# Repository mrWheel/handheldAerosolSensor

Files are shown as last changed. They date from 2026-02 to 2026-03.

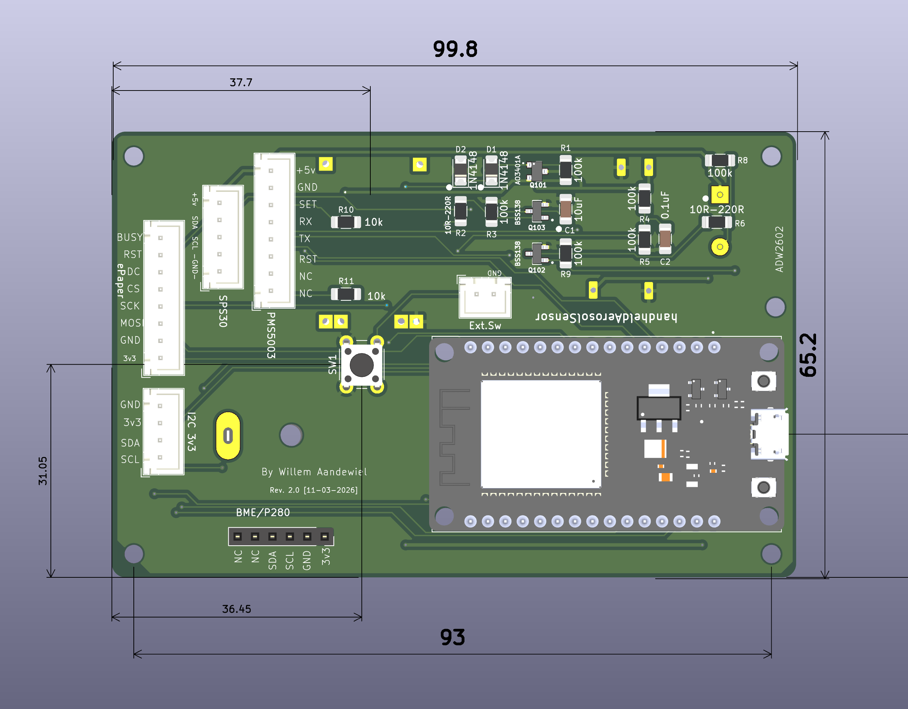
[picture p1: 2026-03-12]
documents/handheldAerosolSensorPCB.png

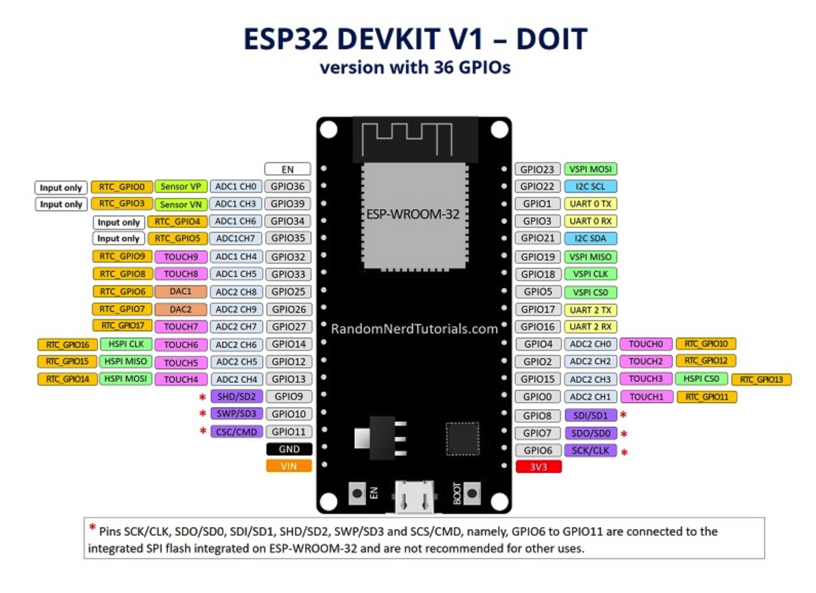
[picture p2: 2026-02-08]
documents/ESP32 DEVKIT V1 (36pins).png

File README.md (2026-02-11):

# Low-Power Air Quality Monitor (SPS30 + E-Paper)

## Disclaimer
This software is developed incrementally. That means I have no clear idea how it works (though it *mostly* does).

If you have questions about this software, it will probably take you just as long to figure things out as it would take me. So I’d prefer that you investigate it yourself.

Having said that **Don’t Even Think About Using It**

Seriously. Don’t.

Building this design may injure or kill you during construction, burn your house down while in use, and then—just to be thorough—explode afterward.

This is **not** a joke. This project involves **lethal voltages**. If you are not a **qualified electronics engineer**, close this repository, step away from the soldering iron, and make yourself a cup of tea.

If you decide to ignore all of the above and build it anyway, you do so **entirely at your own risk**. You are fully responsible for taking proper safety precautions. I take **zero responsibility** for anything that happens—electrically, mechanically, chemically, spiritually, or otherwise.

Also, full disclosure: I am **not** a qualified electrical engineer. I provide **no guarantees**, **no warranties**, and **absolutely no assurance** that this design is correct, safe, or suitable for any purpose whatsoever.

# What it is
This project is a **battery-powered, low-power air quality monitor** based on:

- **ESP32 DEVKIT V1**
- **Sensirion SPS30** particulate matter sensor (I²C)
- **1.54" black/white e‑paper display (200×200)**
- **High-side power latch** using a P‑channel MOSFET + 2N7000 or BSS138
- **Single-cell Li‑ion (18650)** battery with DC/DC boost to 5 V

The system powers itself on with a button, performs a measurement cycle, updates the e‑paper display, and then **fully powers itself off** to achieve near-zero standby current.

---

## Features

- True hardware power-off (no sleep leakage)
- SPS30 warm-up with countdown on e‑paper
- Configurable number of measurement attempts
- **Only valid sensor samples are averaged**
- PM1.0 / PM2.5 / PM10 display
- Simple air-quality classification (PM2.5 based)
- Battery voltage and percentage display

---

## Measurement Flow

1. User presses power button
2. Power latch engages
3. E‑paper resets and shows status
4. SPS30 starts measurement
5. Warm-up delay (default: 15 s)
6. Up to `maxMetingen` measurement attempts
   - Only valid samples are accumulated
7. Average values are calculated
8. Results are shown on the e‑paper
9. SPS30 is stopped
10. Power latch is released (device turns fully off)

---

## Hardware Connections

### ESP32 DevKit V1 - Pin mapping for AerosolSensor

| ESP32 pin | DEVKIT V1 | Standaard functie | AerosolSensor | Opmerking |
|---|---|---|---|---|
| 25 | D25 | GPIO / DAC1 | GPIO_PIN_LATCH | Latch control (OUTPUT) |
| 33 | D33 | GPIO / ADC1_CH5 / Touch | GPIO_PIN_SWITCH | Switch input (INPUT_PULLUP), non-strapping |
| 34 | D34 | ADC1_CH6 (input-only) | GPIO_PIN_BAT_ADC | Battery ADC (input-only), ADC1 recommended |
| 21 | D21 | I2C SDA (typical) | GPIO_PIN_SPS30_SDA | SPS30 SDA |
| 22 | D22 | I2C SCL (typical) | GPIO_PIN_SPS30_SCL | SPS30 SCL |
| 16 | RX2 | Future Ext. | GPIO_PIN_SPS_UART_RX | Serial SPS module |
| 17 | TX2 | Future Ext. | GPIO_PIN_SPS_UART_TX | Serial SPS module | 
| 23 | D23 | VSPI MOSI (typical) | GPIO_PIN_EPD_MOSI | E-paper DIN (MOSI) |
| -1 | n.c. | n.v.t. | GPIO_PIN_EPD_MISO | Not connected on display |
| 18 | D18 | VSPI SCK (typical) | GPIO_PIN_EPD_SCK | E-paper CLK (SCK) |
| 27 | D27 | GPIO | GPIO_PIN_EPD_CS | E-paper CS |
| 19 | D19 | e-Paper DC | GPIO_PIN_EPD_DC | E-paper DC |
| 13 | D13 | e-Paper RST | GPIO_PIN_EPD_RST | E-paper RST |
| 32 | D32 | GPIO / ADC1_CH4 / Touch | GPIO_PIN_EPD_BUSY | E-paper BUSY (INPUT_PULLUP), non-strapping |
| 14 | D14 | GPIO PWM Touch | GPIO_PIN_BUZZER_PWM  | Buzzer 

### Battery Measurement

- 100 kΩ / 100 kΩ divider from battery to D34
- Optional 100 nF capacitor from D34 to GND

---

## Software Stack

- **PlatformIO**
- **Arduino framework**
- **Libraries**
  - GxEPD2
  - Adafruit GFX
  - Adafruit BMP280 Library
  - Adafruit Unified Sensor
  - Sensirion SPS30 (GitHub)
  - safeTimers

---

## PlatformIO Configuration

```ini
; platformio.ini
;
;— ESP32 + Arduino framework
;— Pin choices avoid ESP32 strapping pins (GPIO0,2,4,5,12,15) and flash pins (GPIO6–11).
;— Battery ADC uses ADC1 (GPIO34) so it keeps working even if WiFi were enabled.
;— SPI uses VSPI defaults for ESP32: MOSI=23, MISO=19, SCK=18.

[platformio]
workspace_dir = .pio.nosync
default_envs = esp32dev

[env:esp32dev]
platform = espressif32
board = esp32dev
framework = arduino

monitor_speed = 115200
upload_speed = 921600

;-- do NOT use 0, 2, 4, 5, 12, 15 (Strapping pins) or 6–11 (Flash pins)
build_flags =
  ;==================== Power & user input ====================
  ;— Power latch control (OUTPUT)
  -D GPIO_PIN_LATCH=25

  ;— User pushbutton (INPUT_PULLUP, LOW = pressed)
  -D GPIO_PIN_SWITCH=33

  ;==================== Battery measurement ====================
  ;— Battery voltage divider ADC input (ADC1)
  -D GPIO_PIN_BAT_ADC=34

  ;==================== SPS air quality sensor ====================
  ;— SPS I2C interface
  -D GPIO_PIN_SPS_SDA=21
  -D GPIO_PIN_SPS_SCL=22

  ;— SPS UART interface (UART2, hardware default pins)
  -D GPIO_PIN_SPS_UART_TX=17
  -D GPIO_PIN_SPS_UART_RX=16

  ;==================== E-paper display (SPI) ====================
  ;— SPI data pins (VSPI defaults)
  -D GPIO_PIN_EPD_MOSI=23
  -D GPIO_PIN_EPD_MISO=-1
  -D GPIO_PIN_EPD_SCK=18

  ;— E-paper control pins
  -D GPIO_PIN_EPD_CS=27
  -D GPIO_PIN_EPD_DC=19
  -D GPIO_PIN_EPD_RST=13
  -D GPIO_PIN_EPD_BUSY=32

  ;==================== User feedback ====================
  ;— Piezo buzzer (PWM via LEDC)
  -D GPIO_PIN_BUZZER_PWM=14

  ;==================== Application configuration ====================
  -D WARMUP_SECONDS=5
  -D MAX_METINGEN=5

  ;==================== ADC calibration ====================
  -D ADC_VREF_VOLTAGE=3.30f
  
  ;==================== Battery calibration ====================
  -D BAT_CAL_GAIN=0.94245f
  -D BAT_CAL_OFFSET=0.48763f

  ;==================== Library configuration ====================
  -D DISABLE_DIAGNOSTIC_OUTPUT

lib_deps =
  zinggjm/GxEPD2@^1.6.5
  adafruit/Adafruit GFX Library@^1.11.9
  adafruit/Adafruit BMP280 Library
	adafruit/Adafruit Unified Sensor
  https://github.com/Sensirion/arduino-sps.git
  https://github.com/mrWheel/safeTimers.git
```

---

## Power Latch Notes

- Upload firmware with **stable power** (USB directly)
- During normal operation the latch cuts power completely
- GPIO D25 must be set HIGH early in `setup()` to hold power

---

## Customization

You can easily adjust:

- `warmupSeconds` (e.g. 15 → 30)
- `maxMetingen` (e.g. 5 → 10)
- PM2.5 thresholds for status classification
- Display layout and fonts

---

## License

This project is intended for personal and educational use.
You are free to modify and adapt it for your own hardware.

---

## Notes

This design prioritizes:
- Measurement correctness
- Ultra-low standby power
- Robust behavior on battery power

It is well suited for **portable or infrequently-used air quality measurements** where long battery life matters.

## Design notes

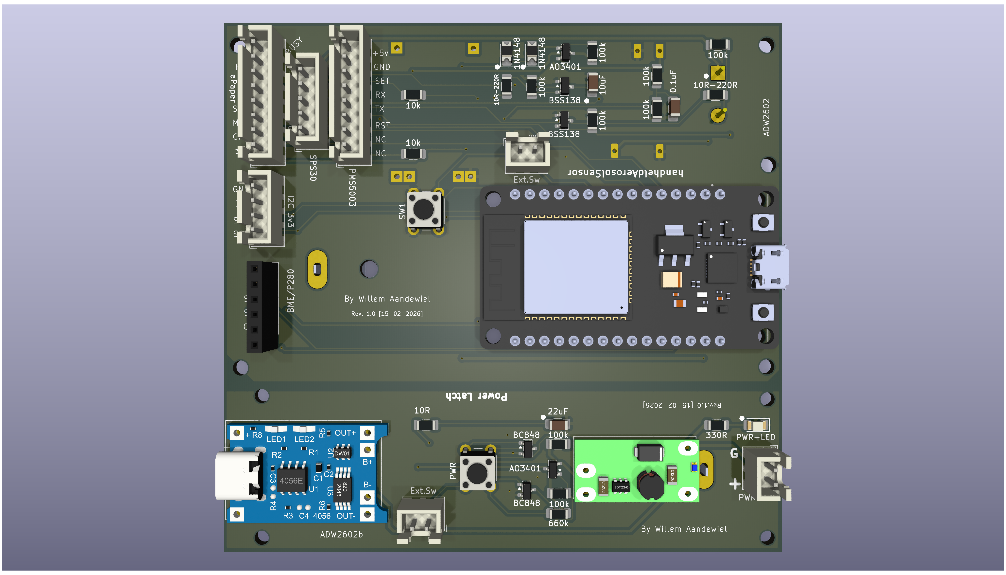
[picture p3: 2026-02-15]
documents/hAS_Top.png

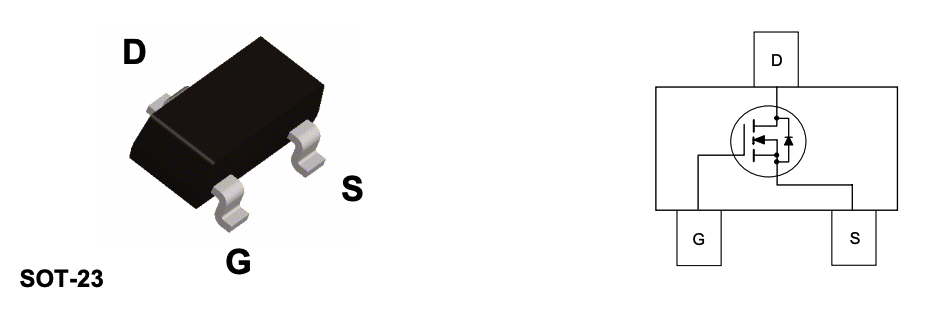
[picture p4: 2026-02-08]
documents/BSS138.png

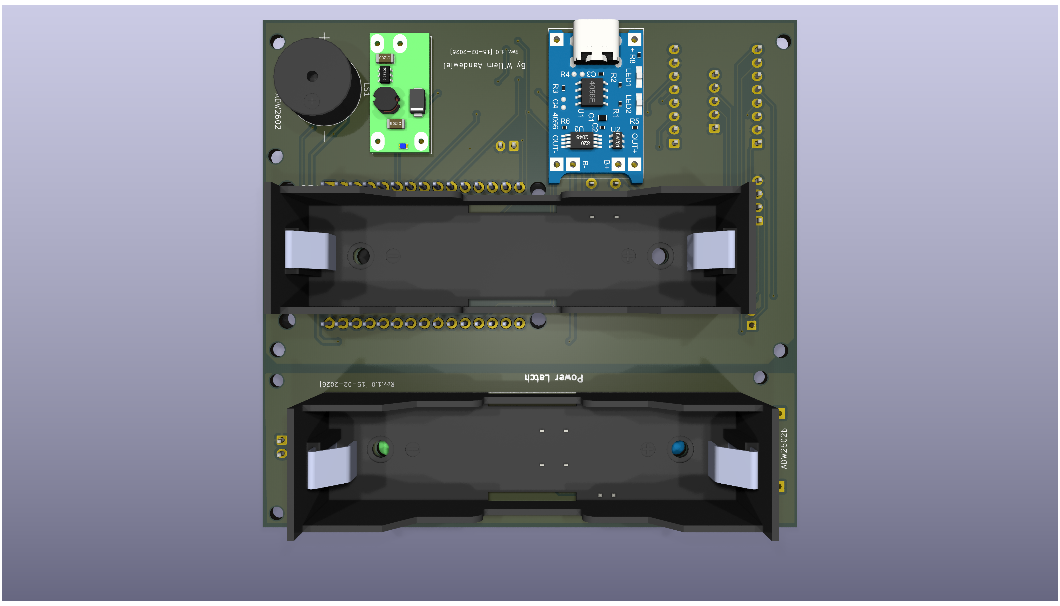
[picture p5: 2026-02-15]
documents/hAS_Bottom.png

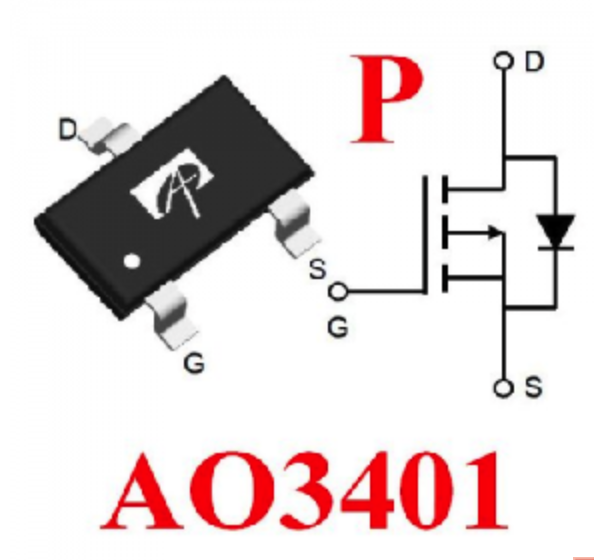
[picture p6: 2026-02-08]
documents/AO3401.png

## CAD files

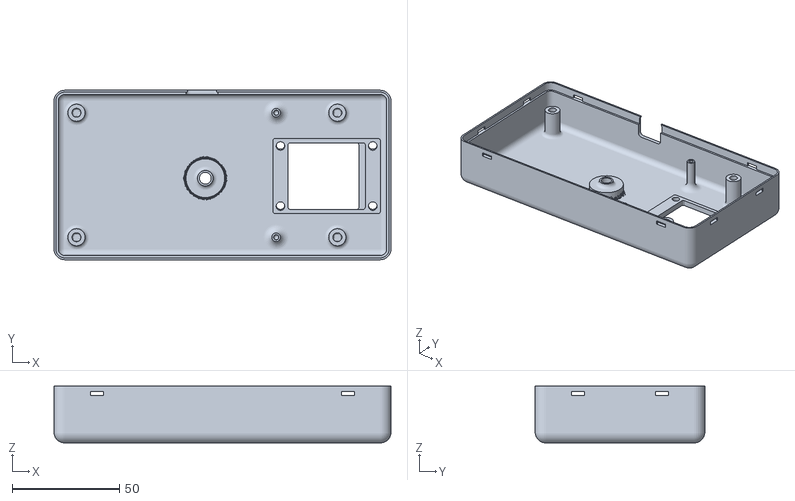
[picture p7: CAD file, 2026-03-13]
3Dfiles/handheldAerosolSensorLid.stl
157.0 x 79.0 x 26.5

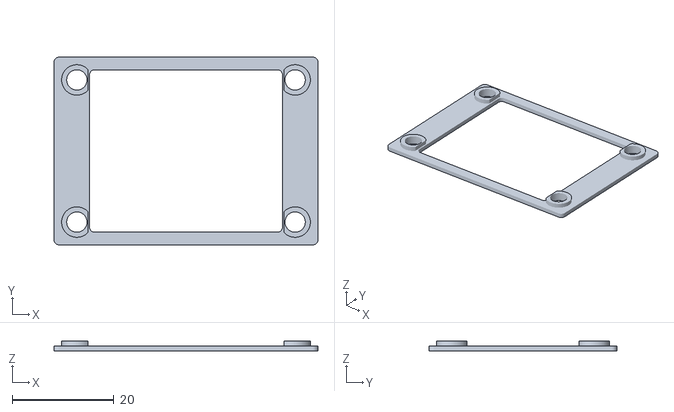
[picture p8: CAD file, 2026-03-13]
documents/ePaper.stl
52.0 x 37.0 x 2.00

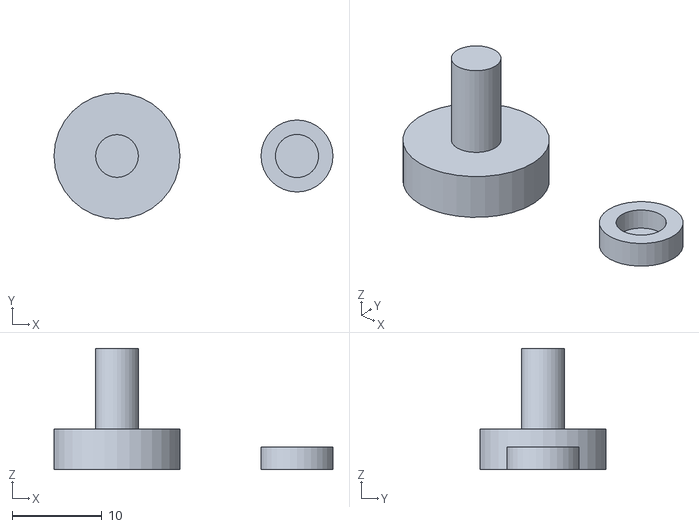
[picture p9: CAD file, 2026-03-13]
3Dfiles/handheldAerosolSensorButton.stl
31.0 x 14.0 x 13.5

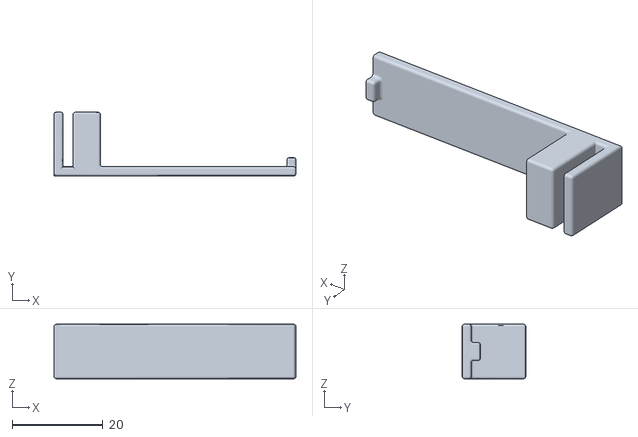
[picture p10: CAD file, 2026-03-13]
documents/SPS30Holder.stl
53.2 x 14.0 x 12.0

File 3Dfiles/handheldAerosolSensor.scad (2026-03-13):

//-----------------------------------------------------------------------
// Yet Another Parameterized Projectbox generator
//
//  This is a box for a handheldAerosolSensor
//
//  Version 1.0.0 (13-03-2026)
//
// This design is parameterized based on the size of a PCB.
//
// For many/complex cutoutGrills, you might need to adjust
//  the max number of elements in OpenSCAD:
//
//      Preferences->Advanced->Turn off rendering at 250000 elements
//                                                   ^^^^^^
//
//-----------------------------------------------------------------------

include <./YAPPgenerator_v3.3.8.scad>

$fn=20;

myPcb    = "../documents/handheldAerosolSensorPCB.stl"; 
myEpaper = "../documents/ePaper.stl"; 

if (false)
{
  translate([56.8, 39.5 , 25.7]) 
  {
    rotate([0,0,180]) color("gray") import(myPcb);
  }
}

if (false)
{
  translate([127, 138,0]) 
  {
    rotate([0,0,180]) color("black") import(myEpaper);
  }
}

//---------------------------------------------------------
// This design is parameterized based on the size of a PCB.
//---------------------------------------------------------
// Note: length/lengte refers to X axis, 
//       width/breedte refers to Y axis,
//       height/hoogte refers to Z axis

/*
      padding-back|<------pcb length --->|<padding-front
                            RIGHT
        0    X-axis ---> 
        +----------------------------------------+   ---
        |                                        |    ^
        |                                        |   padding-right 
      Y |                                        |    v
      | |    -5,y +----------------------+       |   ---              
 B    a |         | 0,y              x,y |       |     ^              F
 A    x |         |                      |       |     |              R
 C    i |         |                      |       |     | pcb width    O
 K    s |         |                      |       |     |              N
        |         | 0,0              x,0 |       |     v              T
      ^ |    -5,0 +----------------------+       |   ---
      | |                                        |    padding-left
      0 +----------------------------------------+   ---
        0    X-as --->
                          LEFT
*/


//-- which part(s) do you want to print?
printBaseShell        = true;
printLidShell         = true;
printSwitchExtenders  = true;
printDisplayClips     = false;

// ********************************************************************
// The Following will be used as the first element in the pbc array

//Defined here so you can define the "Main" PCB using these if wanted
pcbLength           = 100; // front to back (X axis)
pcbWidth            =  65; // side to side (Y axis)
pcbThickness        = 1.7; 
standoffHeight      = 22; //10.1; //-- How much the PCB needs to be raised from the base to leave room for solderings and whatnot
standoffDiameter    = 4;
standoffPinDiameter = 2.0;
standoffHoleSlack   = 0.4;

//===================================================================
// *** PCBs ***
// Printed Circuit Boards
//-------------------------------------------------------------------
//  Default origin =  yappCoordPCB : yappCoordBoxInside[0,0,0]
//
//  Parameters:
//   Required:
//    p(0) = name
//    p(1) = length
//    p(2) = width
//    p(3) = posx
//    p(4) = posy
//    p(5) = Thickness
//    p(6) = standoff_Height = Height to bottom of PCB from the inside of the base
//             negative measures from inside of the lid to the top of the PCB
//    p(7) = standoff_Diameter
//    p(8) = standoff_PinDiameter
//   Optional:
//    p(9) = standoff_HoleSlack (default to 0.4)

//The following can be used to get PCB values elsewhere in the script - not in pcb definition. 
//If "PCB Name" is omitted then "Main" is used
//  pcbLength           --> pcbLength("PCB Name")
//  pcbWidth            --> pcbWidth("PCB Name")
//  pcbThickness        --> pcbThickness("PCB Name") 
//  standoffHeight      --> standoffHeight("PCB Name") 
//  standoffDiameter    --> standoffDiameter("PCB Name") 
//  standoffPinDiameter --> standoffPinDiameter("PCB Name") 
//  standoffHoleSlack   --> standoffHoleSlack("PCB Name") 

pcb = 
[
  // Default Main PCB - DO NOT REMOVE the "Main" line.
  //-- 0,          1,        2, 3, 4,            5,              6,                7,                   8, 9
  ["Main", pcbLength, pcbWidth, 0, 0, pcbThickness, standoffHeight, standoffDiameter, standoffPinDiameter, standoffHoleSlack]
  //--   0,   1,  2,   3, 4, 5,  6, 7, 8, 9
 ,["ePaper", 33, 48, 100, 9, 3, -0.1, 5, 2, 0.5]

];

//-------------------------------------------------------------------                            
//-- padding between pcb and inside wall
paddingFront        = 15;
paddingBack         = 5;
paddingRight        = 5;
paddingLeft         = 5;

//-- Edit these parameters for your own box dimensions
wallThickness       = 2.0;
basePlaneThickness  = 2.0;
lidPlaneThickness   = 2.0;

//-- Total height of box = lidPlaneThickness 
//                       + lidWallHeight 
//--                     + baseWallHeight 
//                       + basePlaneThickness
//-- space between pcb and lidPlane :=
//--      (bottonWallHeight+lidWallHeight) - (standoffHeight+pcbThickness)
baseWallHeight      = 20;
lidWallHeight       = 20;

//-- ridge where base and lid off box can overlap
//-- Make sure this isn't less than lidWallHeight
ridgeHeight         = 5.0;
ridgeSlack          = 0.2; // Gap between the inside of the lid and the outside of the base
//New in v3.3.7 
ridgeGap            = 0.5; // Gap between the bottom of the base ridge and the bottom of the lid when assembled.
roundRadius         = 5.0;

// Box Types are 0-4 with 0 as the default
// 0 = All edges rounded with radius (roundRadius) above
// 1 = All edges sqrtuare
// 2 = All edges chamfered by (roundRadius) above 
// 3 = Square top and bottom edges (the ones that touch the build plate) and rounded vertical edges
// 4 = Square top and bottom edges (the ones that touch the build plate) and chamfered vertical edges
// 5 = Chanfered top and bottom edges (the ones that touch the build plate) and rounded vertical edges
boxType             = 0; // Default type 0

// Set the layer height of your printer
printerLayerHeight  = 0.2;


//---------------------------
//--     C O N T R O L     --
//---------------------------
// -- Render --
renderQuality             = 8;          //-> from 1 to 32, Default = 8

// --Preview --
previewQuality            = 5;          //-> from 1 to 32, Default = 5
showSideBySide            = true;       //-> Default = true
onLidGap                  = 1;  // tip don't override to animate the lid opening
colorLid                  = "YellowGreen";   
alphaLid                  = 1;
colorBase                 = "BurlyWood";
alphaBase                 = 1;
hideLidWalls              = false;      //-> Remove the walls from the lid : only if preview and showSideBySide=true 
hideBaseWalls             = false;      //-> Remove the walls from the base : only if preview and showSideBySide=true  
showOrientation           = true;       //-> Show the Front/Back/Left/Right labels : only in preview
showPCB                   = false;      //-> Show the PCB in red : only in preview 
showSwitches              = false;      //-> Show the switches (for pushbuttons) : only in preview 
showButtonsDepressed      = false;      //-> Should the buttons in the Lid On view be in the pressed position
showOriginCoordBox        = false;      //-> Shows red bars representing the origin for yappCoordBox : only in preview 
showOriginCoordBoxInside  = false;      //-> Shows blue bars representing the origin for yappCoordBoxInside : only in preview 
showOriginCoordPCB        = false;      //-> Shows blue bars representing the origin for yappCoordBoxInside : only in preview 
showMarkersPCB            = false;      //-> Shows black bars corners of the PCB : only in preview 
showMarkersCenter         = false;      //-> Shows magenta bars along the centers of all faces  
inspectX                  = 0;          //-> 0=none (>0 from Back)
inspectY                  = 0;          //-> 0=none (>0 from Right)
inspectZ                  = 0;          //-> 0=none (>0 from Bottom)
inspectXfromBack          = true;       //-> View from the inspection cut foreward
inspectYfromLeft          = true;       //-> View from the inspection cut to the right
inspectZfromBottom        = true;       //-> View from the inspection cut up
//---------------------------
//--     C O N T R O L     --
//---------------------------

//-------------------------------------------------------------------
//-------------------------------------------------------------------
// Start of Debugging config (used if not overridden in template)
// ------------------------------------------------------------------
// ------------------------------------------------------------------
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

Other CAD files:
3Dfiles/YAPPgenerator_v3.3.8.scad
3Dfiles/YAPPgenerator_v3.0.2.scad

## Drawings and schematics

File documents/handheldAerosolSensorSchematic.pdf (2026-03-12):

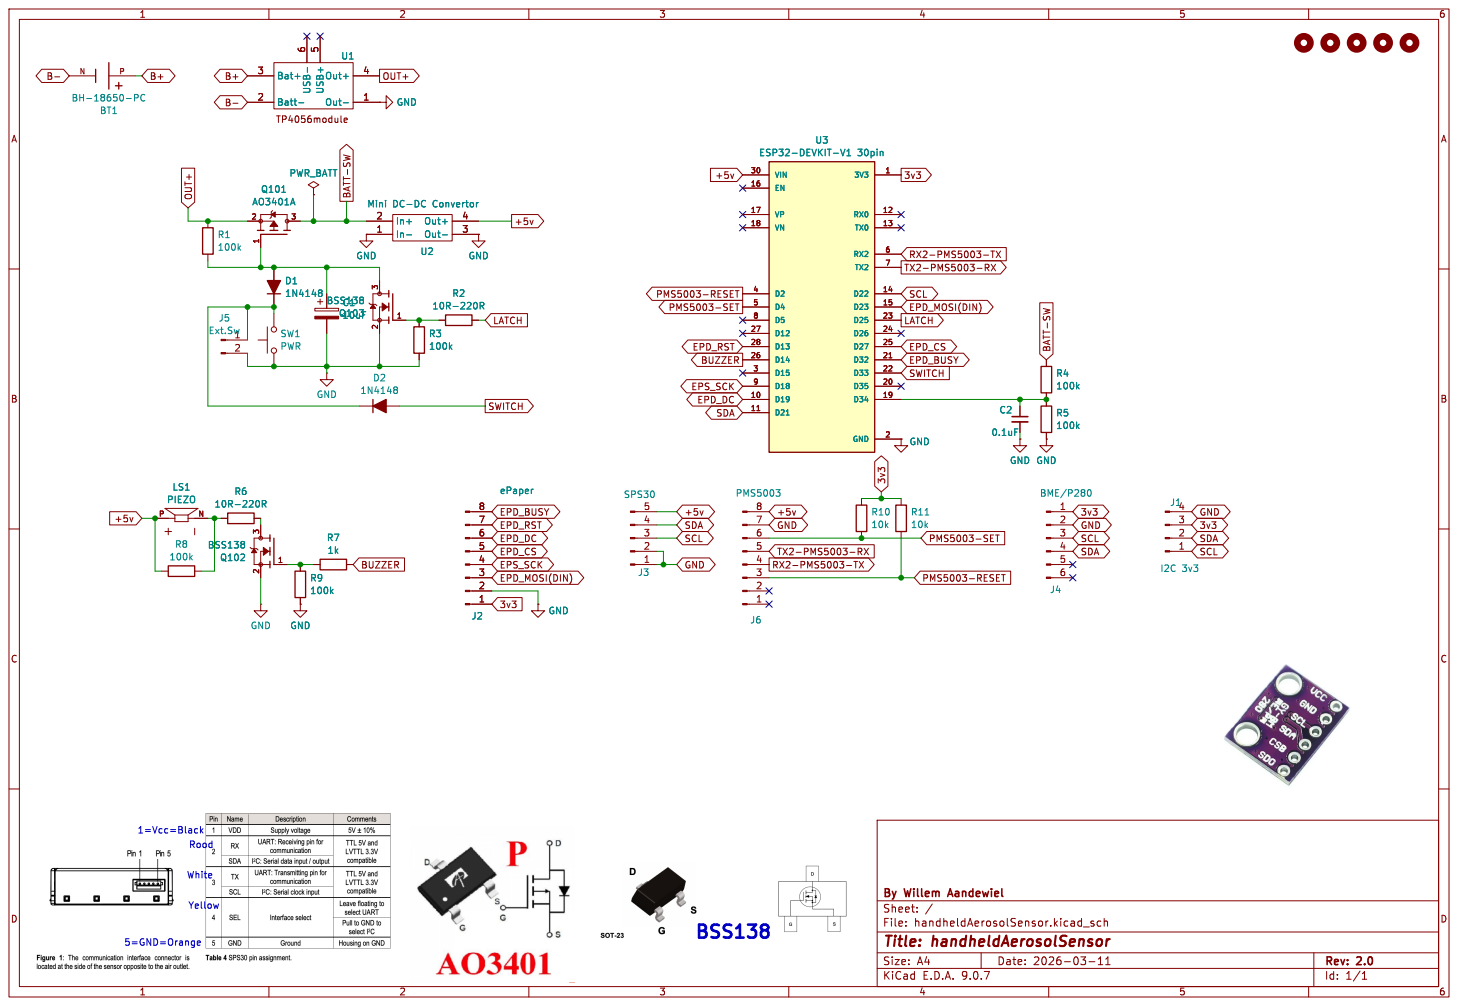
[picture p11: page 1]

Id: 1/1 Title: handheldAerosolSensor File: handheldAerosolSensor.kicad_sch Sheet: / By Willem Aandewiel

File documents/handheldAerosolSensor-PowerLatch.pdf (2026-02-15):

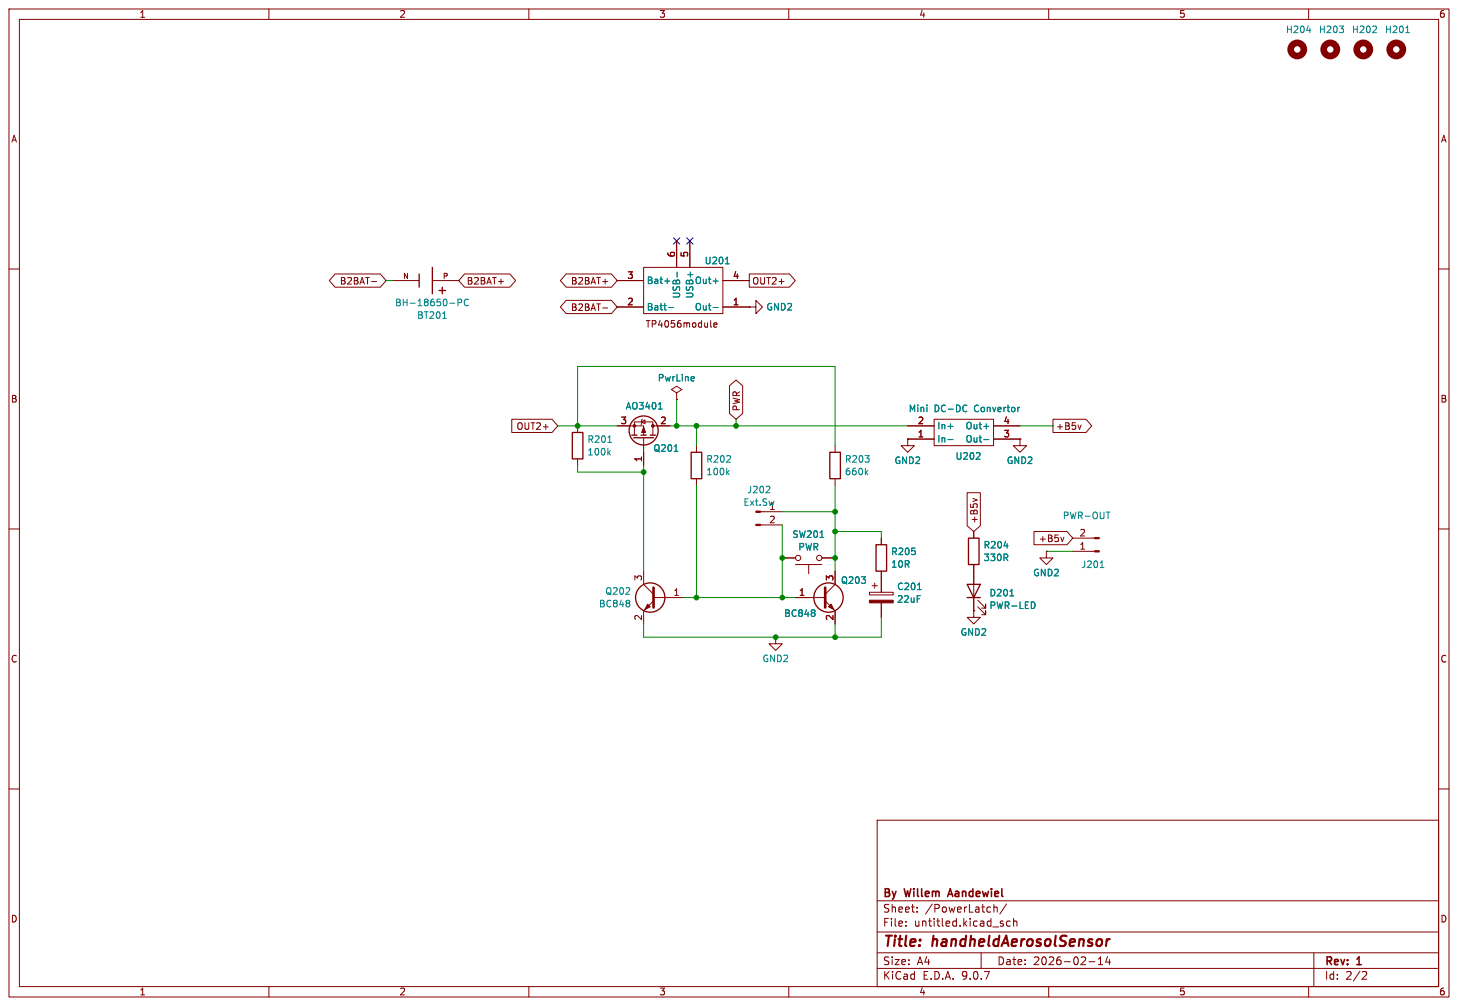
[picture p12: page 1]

5 USB- 6 Batt- 2 Bat+ 3 U201 PwrLine GND2 +B5v B2BAT+ B2BAT- +B5v +B5v B2BAT- B2BAT+ OUT2+ OUT2+ PWR Q201 AO3401

5 USB- 6 Batt- 2 Bat+ 3 PwrLine GND2 Q203 BC848

Id: 2/2 Title: handheldAerosolSensor File: untitled.kicad_sch Sheet: /PowerLatch/ By Willem Aandewiel

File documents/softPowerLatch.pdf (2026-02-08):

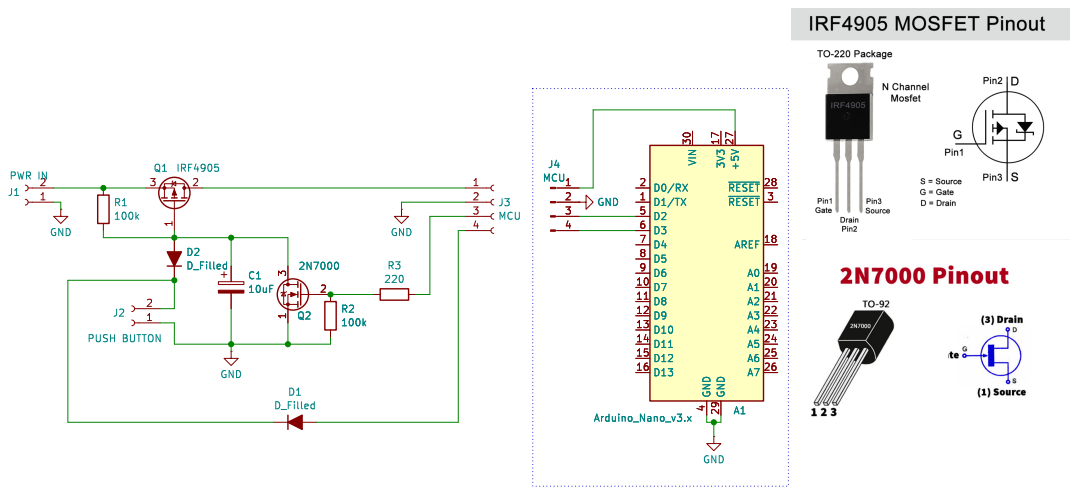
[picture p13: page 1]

Id: 1/1 Title: File: softPowerLatch.kicad_sch Sheet: /

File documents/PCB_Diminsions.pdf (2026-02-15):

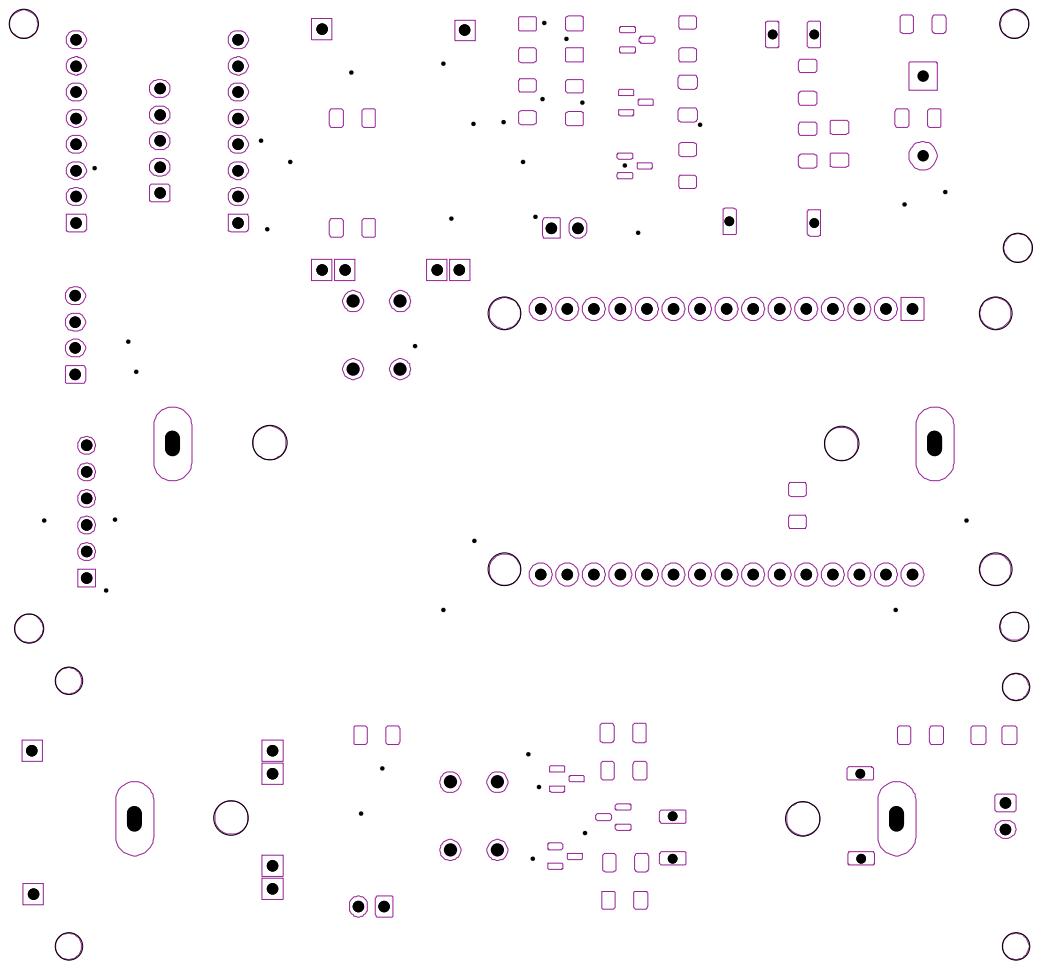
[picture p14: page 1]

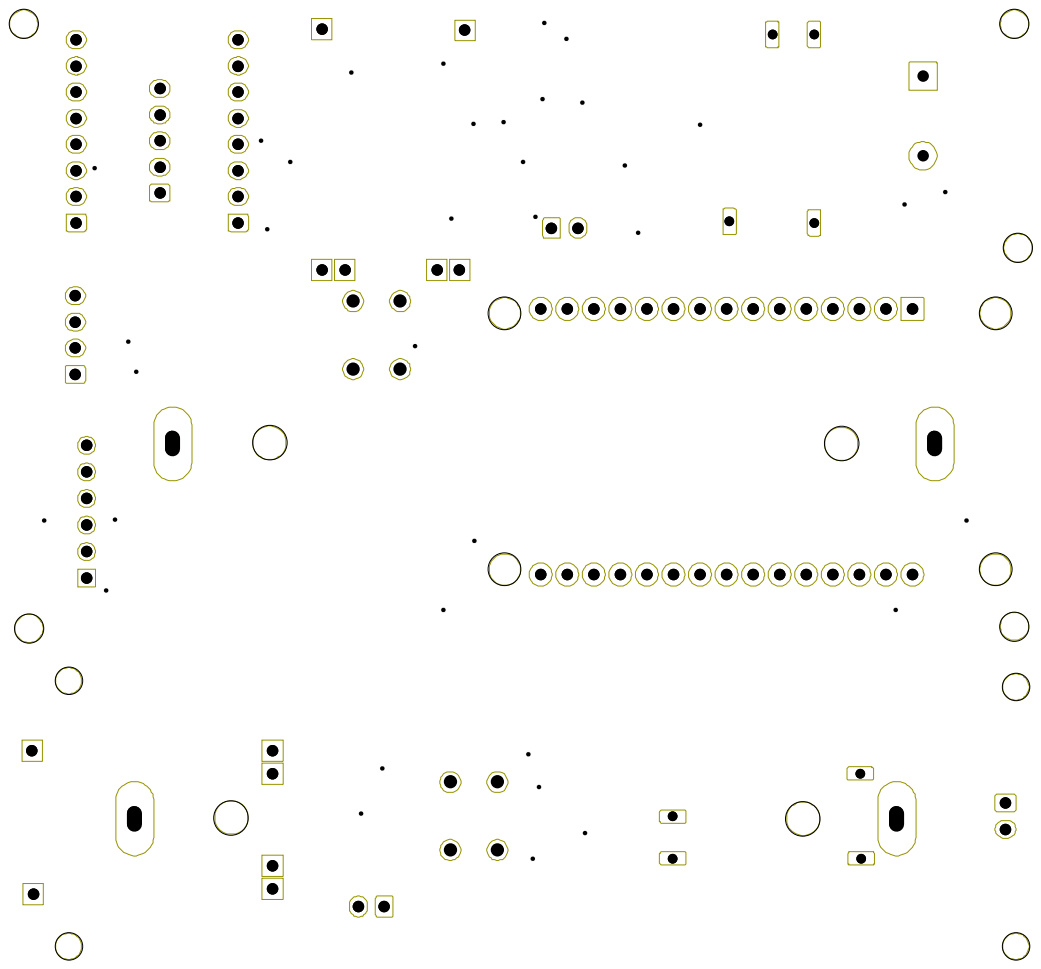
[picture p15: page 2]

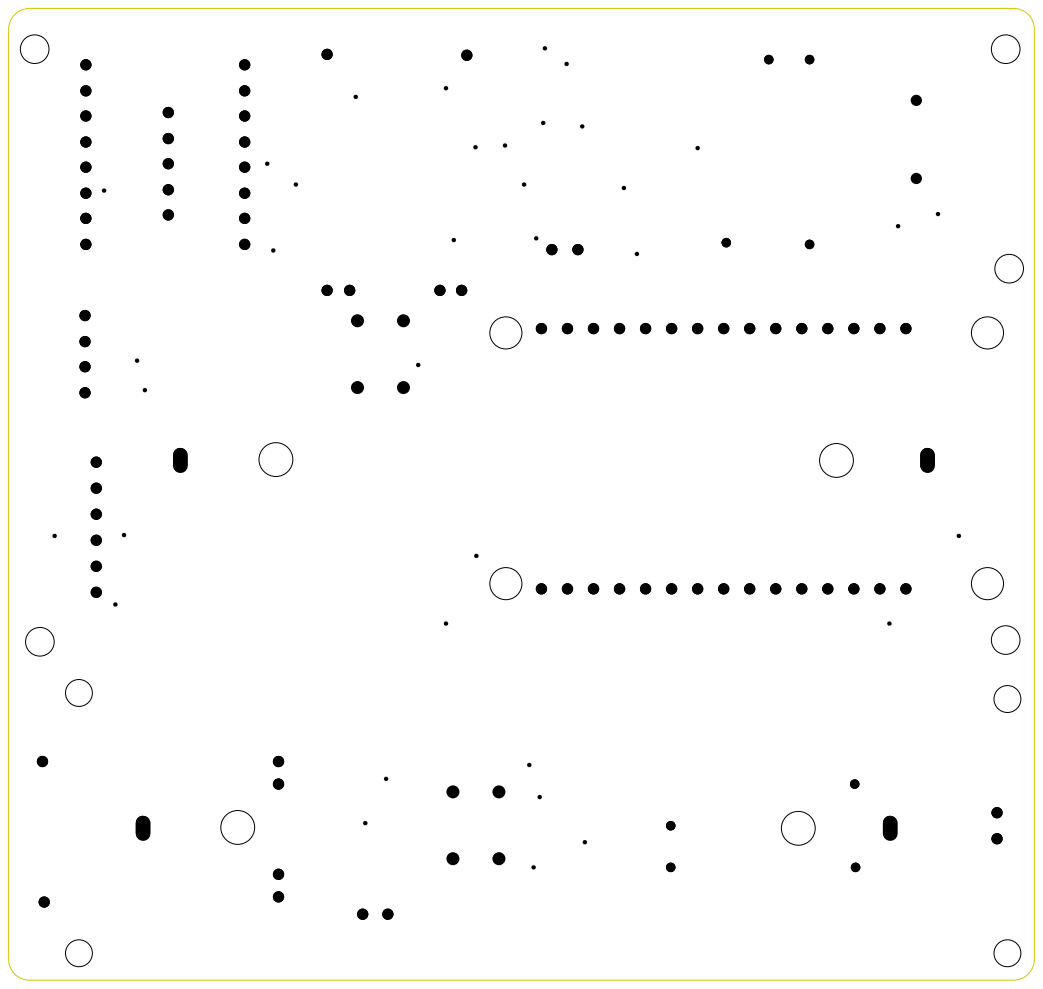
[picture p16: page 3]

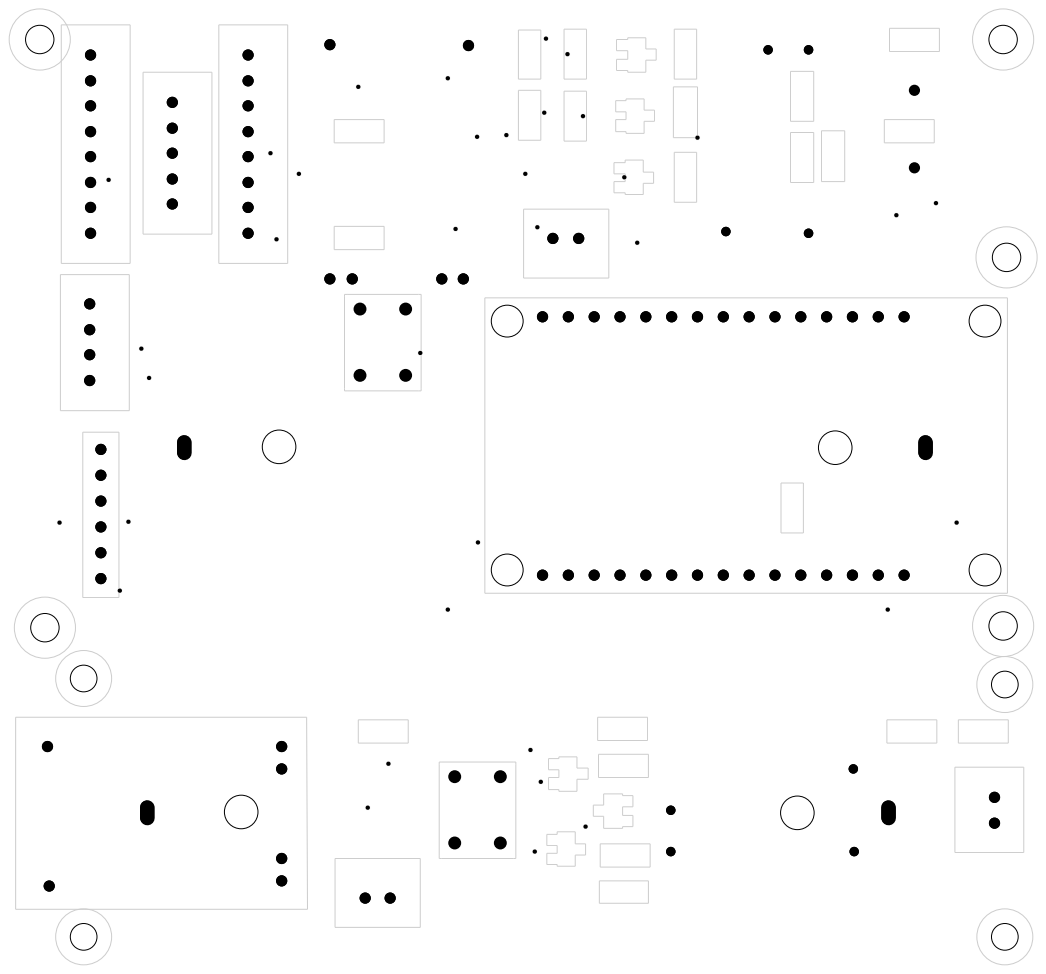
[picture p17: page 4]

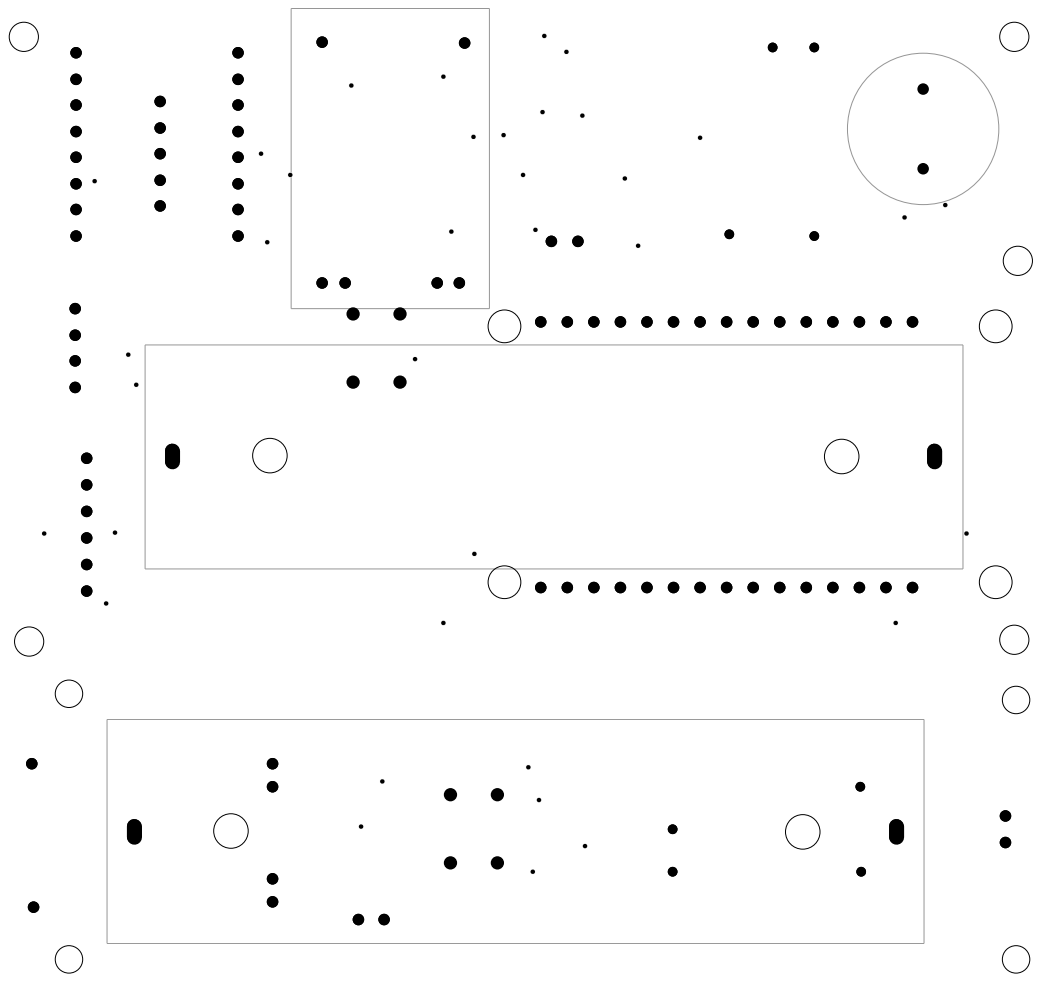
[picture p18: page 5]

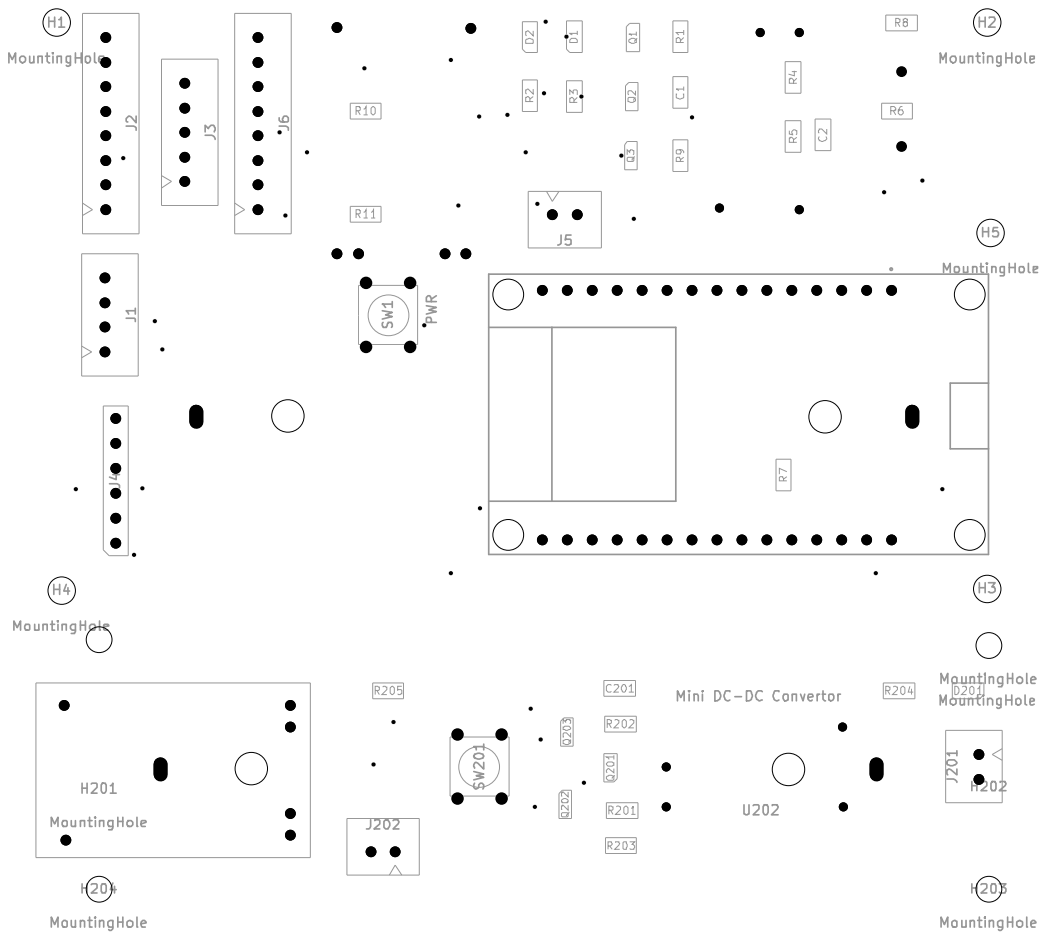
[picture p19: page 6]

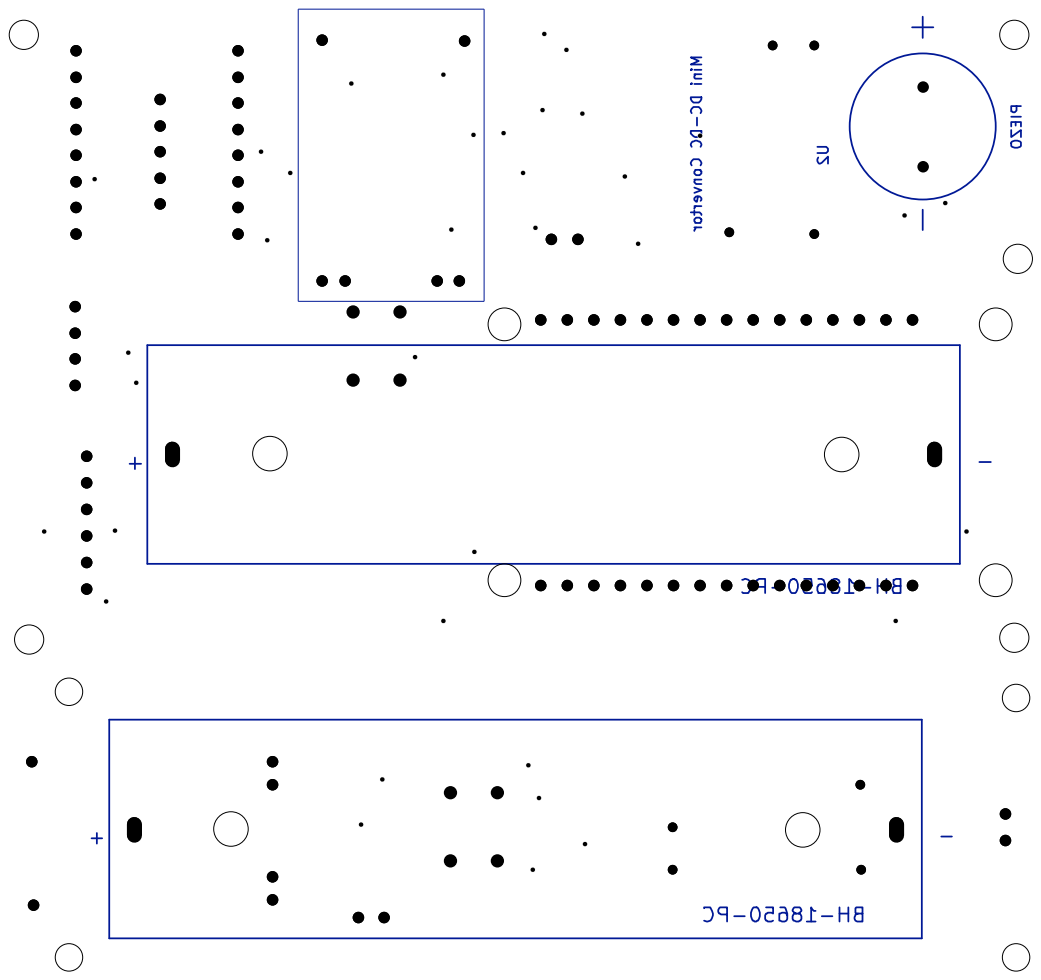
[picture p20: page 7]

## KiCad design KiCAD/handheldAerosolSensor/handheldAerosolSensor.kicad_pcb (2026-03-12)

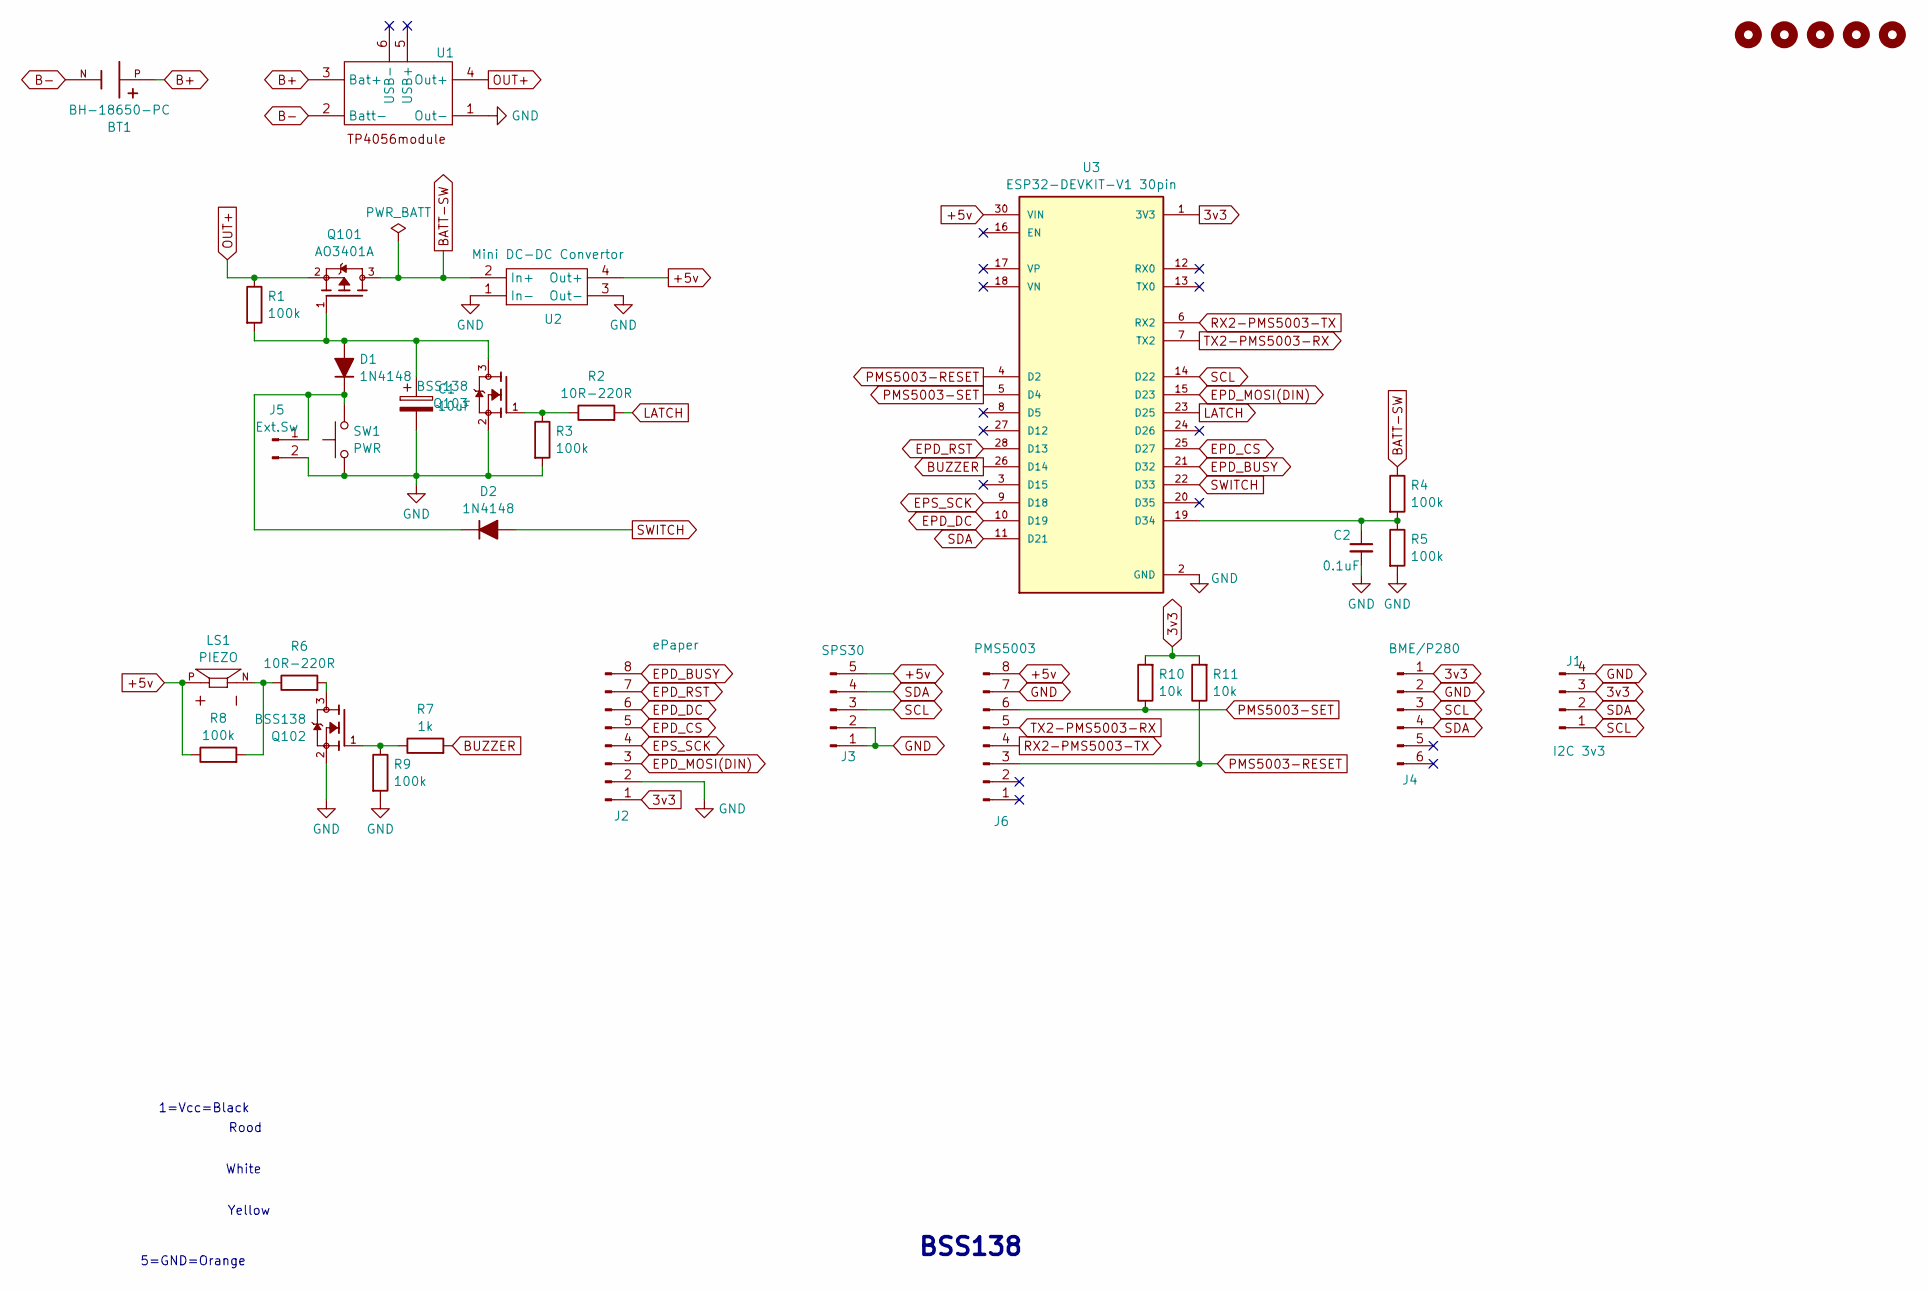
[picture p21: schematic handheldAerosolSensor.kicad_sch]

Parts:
BT1: BH-18650-PC; BAT_BH-18650-PC; PARTREV 05/17/19
C1: 10uF; C_1206_3216Metric_Pad1.33x1.80mm_HandSolder
C2: 0.1uF; C_1206_3216Metric_Pad1.33x1.80mm_HandSolder
D1, D2: 1N4148; D_1206_3216Metric_Pad1.42x1.75mm_HandSolder
H1, H2, H3, H4, H5: MountingHole; MountingHole_2.7mm
J1: I2C 3v3; JST_XH_B4B-XH-A_1x04_P2.50mm_Vertical
J2: ePaper; JST_XH_B8B-XH-A_1x08_P2.50mm_Vertical
J3: SPS30; JST_XH_B5B-XH-A_1x05_P2.50mm_Vertical
J4: BME/P280; PinSocket_1x06_P2.54mm_Vertical
J5: Ext.Sw; JST_XH_B2B-XH-A_1x02_P2.50mm_Vertical
J6: PMS5003; JST_XH_B8B-XH-A_1x08_P2.50mm_Vertical
LS1: PIEZO; XDCR_CPI-148-24-90T-67; PARTREV 1
Q101: AO3401A; AO3401
Q102, Q103: BSS138; PARTREV 30 Jan 2018
R1, R3, R4, R5, R8, R9: 100k; R_1206_3216Metric_Pad1.30x1.75mm_HandSolder
R2, R6: 10R-220R; R_1206_3216Metric_Pad1.30x1.75mm_HandSolder
R7: 1k; R_1206_3216Metric_Pad1.30x1.75mm_HandSolder
R10, R11: 10k; R_1206_3216Metric_Pad1.30x1.75mm_HandSolder
SW1: PWR; SW_PUSH_6mm_H4.3mm
U1: TP4056_USB-Charger_Board
U2: Mini DC-DC Convertor; Mini DC-DC Boost Convertor
U3: ESP32-DEVKIT-V1 30pin; MODULE_ESP32_DEVKIT_V1_30pin; PARTREV N/A

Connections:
3v3: J1.3, J2.1, J4.1, R10.2, R11.2, U3.1 (3V3)
+5v: J3.5, J6.8, LS1.P, R8.1, U2.4 (Out+), U3.30 (VIN)
B+: BT1.P, U1.3 (Bat+)
B-: BT1.N, U1.2 (Batt-)
BATT-SW: Q101.3, R4.1, U2.2 (In+)
BUZZER: R7.2, U3.26 (D14)
EPD_BUSY: J2.8, U3.21 (D32)
EPD_CS: J2.5, U3.25 (D27)
EPD_DC: J2.6, U3.10 (D19)
EPD_MOSI(DIN): J2.3, U3.15 (D23)
EPD_RST: J2.7, U3.28 (D13)
EPS_SCK: J2.4, U3.9 (D18)
GND: C1.2, C2.2, J1.4, J2.2, J3.1, J3.2, J4.2, J5.2, J6.7, Q102.2, Q103.2, R3.2, R5.2, R9.2, SW1.1, U1.1 (Out-), U2.1 (In-), U2.3 (Out-), U3.2 (GND), U3.29 (GND)
LATCH: R2.2, U3.23 (D25)
unnamed: C1.1, D1.2 (A), Q101.1, Q103.3, R1.2
unnamed: D1.1 (K), D2.1 (K), J5.1, SW1.2
unnamed: LS1.N, R6.1, R8.2
unnamed: Q102.1, R7.1, R9.1
unnamed: Q102.3, R6.2
unnamed: Q103.1, R2.1, R3.1
unnamed: C2.1, R4.2, R5.1, U3.19 (D34)
OUT+: Q101.2, R1.1, U1.4 (Out+)
PMS5003-RESET: J6.3, R11.1, U3.4 (D2)
PMS5003-SET: J6.6, R10.1, U3.5 (D4)
RX2-PMS5003-TX: J6.4, U3.6 (RX2)
SCL: J1.1, J3.3, J4.3, U3.14 (D22)
SDA: J1.2, J3.4, J4.4, U3.11 (D21)
SWITCH: D2.2 (A), U3.22 (D33)
TX2-PMS5003-RX: J6.5, U3.7 (TX2)

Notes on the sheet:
1=Vcc=Black
Rood
BSS138
5=GND=Orange
Yellow
White

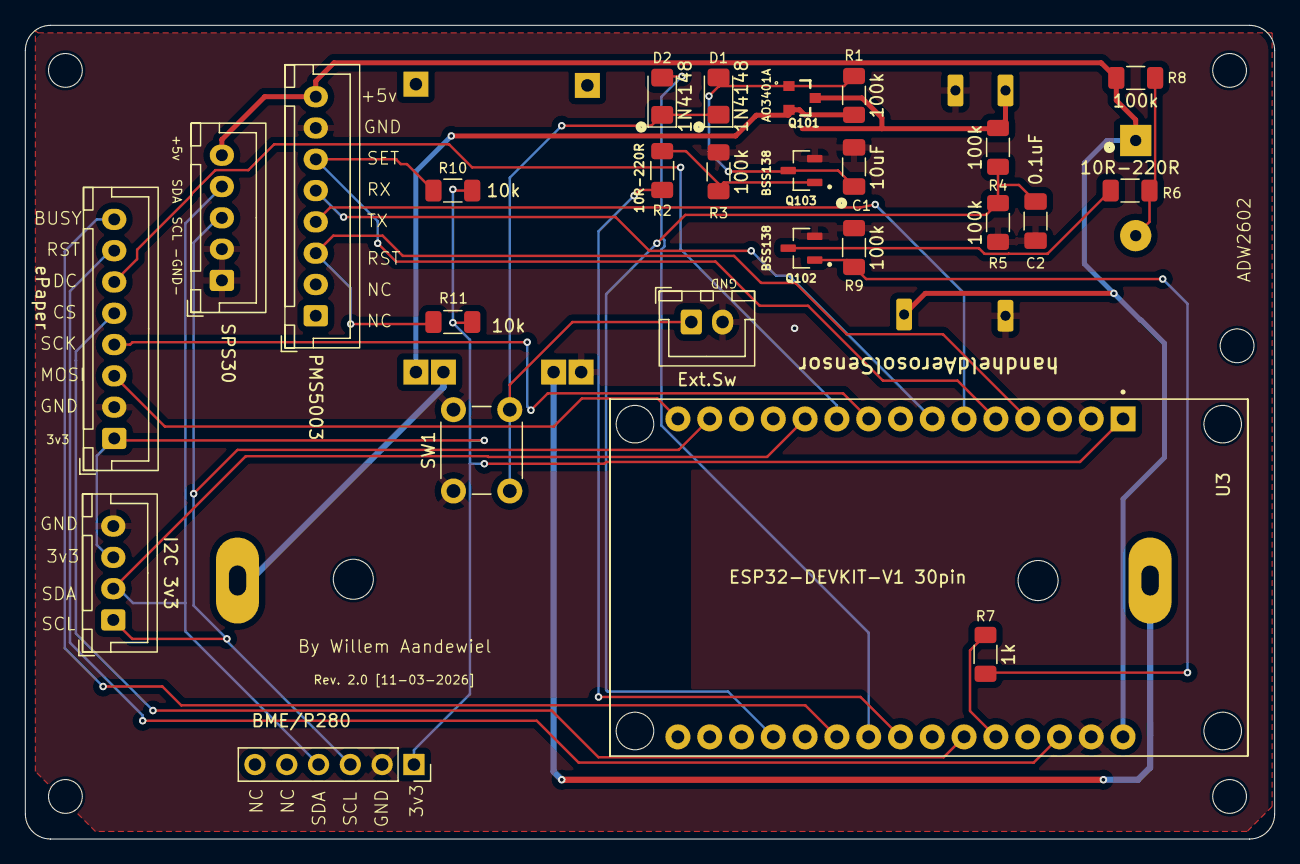
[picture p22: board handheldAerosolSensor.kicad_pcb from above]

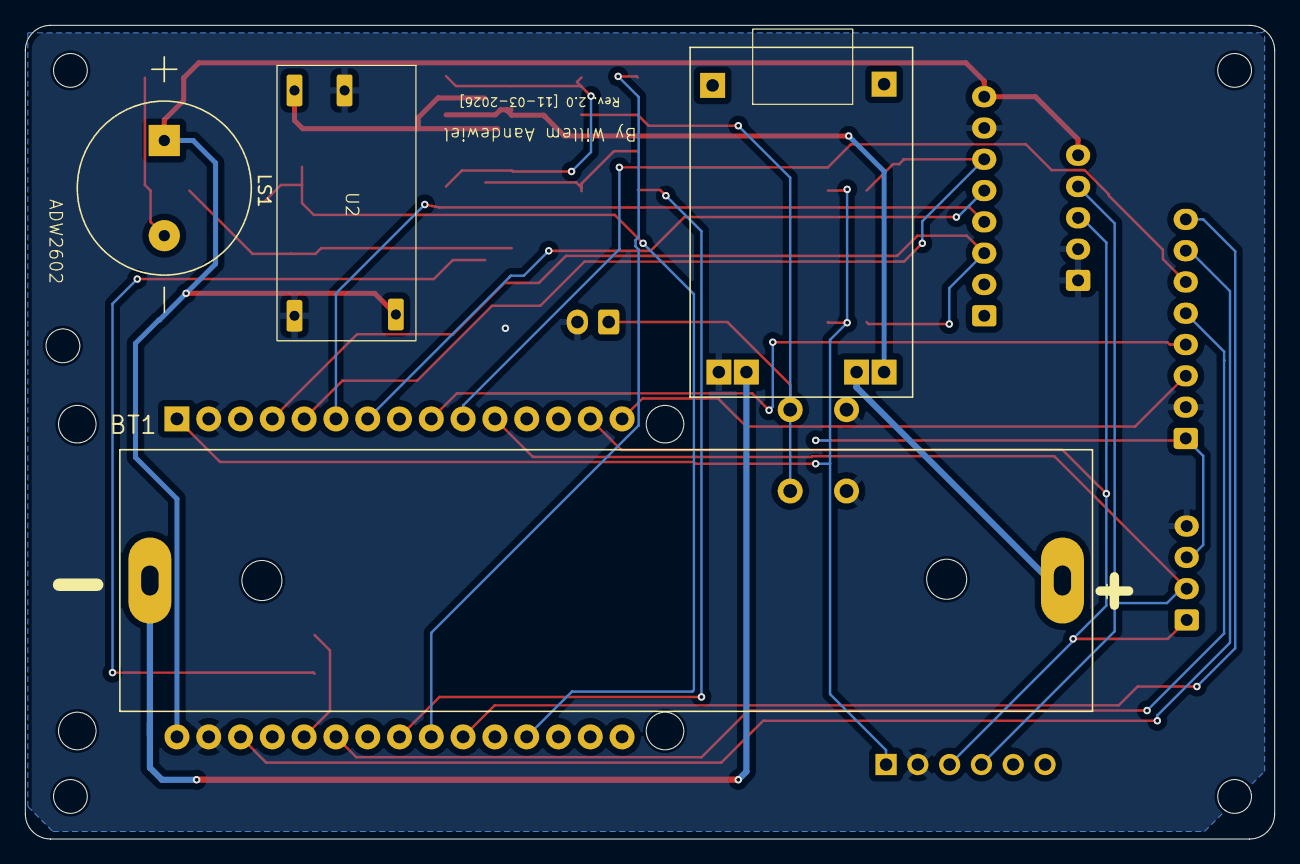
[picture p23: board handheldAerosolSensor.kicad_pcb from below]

Board: 2 copper layers, 99.8 x 65.0 mm, 35 parts (4 on the bottom side), 29 nets.

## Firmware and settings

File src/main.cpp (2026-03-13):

/*** Last Changed: 2026-03-13 - 18:04 ***/
#include <Arduino.h>
#include <Wire.h>
#include <SPI.h>

// — ESP32 radio control to disable WiFi/Bluetooth as early as possible
#include <WiFi.h>
#include <esp_wifi.h>
#include <esp_bt.h>

#include "WiFiManagerExt.h"

// — Display
#include <GxEPD2_BW.h>
#include <Fonts/FreeMonoBold9pt7b.h>
#include <Fonts/FreeMonoBold12pt7b.h>
#include <Fonts/FreeMonoBold18pt7b.h>

// — Sensors
#include <sps30.h>
#include <sensirion_i2c.h>
#include <Adafruit_Sensor.h>
#include <Adafruit_BMP280.h>

// — Timing
#include <safeTimers.h>

// — Program version string (keep manually updated with each release)
// — NEVER CHANGE THIS const char* NAME
// —             vvvvvvvvvvvvvv
static const char* PROG_VERSION = "v1.0.0";
// —             ^^^^^^^^^^^^^^

#ifndef E_PAPER_ROTATION
#define E_PAPER_ROTATION 1
#endif

// ===================== User configuration (from build_flags) =====================

// — Latch control pin (drives the 2N7000 gate through a series resistor)
static const uint8_t pinLatch = GPIO_PIN_LATCH;

// — Pushbutton pin (LOW = pressed with INPUT_PULLUP)
static const uint8_t pinSwitch = GPIO_PIN_SWITCH;

// — Battery divider ADC input (default math assumes 2:1 divider => ADC sees Vbat/2)
static const uint8_t pinBatAdc = GPIO_PIN_BAT_ADC;

// — E-paper SPI pins (from build_flags)
static const int8_t pinEpdMosi = GPIO_PIN_EPD_MOSI;
static const int8_t pinEpdMiso = GPIO_PIN_EPD_MISO;
static const int8_t pinEpdSck = GPIO_PIN_EPD_SCK;

// — E-paper control pins
static const uint8_t pinEpdCs = GPIO_PIN_EPD_CS;
static const uint8_t pinEpdDc = GPIO_PIN_EPD_DC;
static const uint8_t pinEpdRst = GPIO_PIN_EPD_RST;
static const uint8_t pinEpdBusy = GPIO_PIN_EPD_BUSY;
static const uint8_t epdRotation = (uint8_t)E_PAPER_ROTATION;

// — SPS I2C pins (also used for BMP280)
static const uint8_t pinSpsSda = GPIO_PIN_SPS30_SDA;
static const uint8_t pinSpsScl = GPIO_PIN_SPS30_SCL;

// — PMS UART pins (UART2)
static const int8_t pinPms5003UartTx = GPIO_PIN_UART_TX2_PMS5003;
static const int8_t pinPms5003UartRx = GPIO_PIN_UART_RX2_PMS5003;
static const uint8_t pinPms5003Set = GPIO_PIN_PMS5003_SET;
static const uint8_t pinPms5003Reset = GPIO_PIN_PMS5003_RESET;

static HardwareSerial spsUart(2);

enum ParticleSensorType
{
  SENSOR_TYPE_SPS30,
  SENSOR_TYPE_PMS5003
};

static ParticleSensorType activeParticleSensor = SENSOR_TYPE_SPS30;
static WiFiManagerExt wifiManagerExt;

// — BMP280 instance
static Adafruit_BMP280 bmp;
static bool bmpOk = false;

// — Warm-up time after starting SPS measurement
static const uint16_t warmupSeconds = WARMUP_SECONDS;

// — Maximum number of measurement attempts (only valid reads are averaged)
static const uint8_t maxMetingen = MAX_METINGEN;

// — ADC reference voltage used for battery math (calibrate for best accuracy)
static const float adcVref = (float)ADC_VREF_VOLTAGE;

// ===================== Timing (safeTimers) =====================

// — UI + sampling cadence
static const uint32_t warmupTickMs = 1000UL;
static const uint32_t warmupSampleIntervalMs = 5000UL;
static const uint32_t sampleIntervalMs = 2500UL;
static const uint32_t spsAttemptTimeoutMs = 7000UL;
static const uint32_t spsPollIntervalMs = 100UL;

// — Switch handling
static const uint32_t switchDebounceMs = 30UL;
static const uint32_t switchShortPressMs = 2000UL;
static const uint32_t switchLongPressMs = 3000UL;
static const uint32_t switchMultiPressWindowMs = 1500UL;
static const uint32_t switchTaskIntervalMs = 10UL;

// — safeTimers declarations
DECLARE_TIMER_MS(tWarmupTick, warmupTickMs, SKIP_MISSED_TICKS);
DECLARE_TIMER_MS(tWarmupSampleInterval, warmupSampleIntervalMs, SKIP_MISSED_TICKS);
DECLARE_TIMER_MS(tSampleInterval, sampleIntervalMs, SKIP_MISSED_TICKS);
DECLARE_TIMER_MS(tAttemptTimeout, spsAttemptTimeoutMs, SKIP_MISSED_TICKS);
DECLARE_TIMER_MS(tSpsPoll, spsPollIntervalMs, SKIP_MISSED_TICKS);

// ===================== Display selection =====================

// — 1.54" 200x200 B/W display; full height buffer is fine on ESP32
static const uint16_t pageHeight = 200;

// — Display driver instance
#if E_PAPER_VERSION == 1
// — Old Waveshare panel (IL3829)
GxEPD2_BW<GxEPD2_154, pageHeight> display(
    GxEPD2_154(pinEpdCs, pinEpdDc, pinEpdRst, pinEpdBusy));
#elif E_PAPER_VERSION == 2
// — New Waveshare panel (SSD1681)
GxEPD2_BW<GxEPD2_154_D67, pageHeight> display(
    GxEPD2_154_D67(pinEpdCs, pinEpdDc, pinEpdRst, pinEpdBusy));
#else
#error "Error: Unsupported DISPLAY_VERSION"
#endif

// ===================== Fixed layout coordinates =====================

struct UiLayout
{
  int16_t xText;

  int16_t xPmCol1;
  int16_t xPmCol2;
  int16_t xPmCol3;

  int16_t yBattery;
  int16_t yEnv;

  int16_t yPmHeader;
  int16_t yPmValues;

  int16_t yMessage;
};

// — Layout tuned for 200x200, rotation=1
// — 9pt for small lines + PM header
// — 12pt for PM values
static const UiLayout ui =
    {
        4, // xText

        4,   // PM column 1
        70,  // PM column 2
        136, // PM column 3

        26, // yBattery (9pt) -26-
        52, // yEnv (9pt) -48-

        90,  // yPmHeader (9pt) -72-
        128, // yPmValues (12pt) -110-

        183 // yMessage (9pt) -186-
};

// — UI text fields
static String batteryText;
static String envText;
static String pm1Text;
static String pm25Text;
static String pm10Text;
static String messageText;
static uint8_t batteryPercentLast = 0;
static float batteryVoltageLast = 0.0f;
static volatile bool displayRefreshInProgress = false;

// ===================== Text helpers =====================

static String truncateToChars(const String& s, uint8_t maxChars)
{
  if (s.length() <= maxChars)
  {
    return s;
  }

  return s.substring(0, maxChars);

} //   truncateToChars()

// ===================== Air quality classification =====================

enum AirStatus
{
  STATUS_GEMIDDELD,
  STATUS_HOOG,
  STATUS_EXTREEM
};

static AirStatus classifyPm25(float pm25)
{
  if (pm25 < 35.0f)
  {
    return STATUS_GEMIDDELD;
  }

  if (pm25 < 75.0f)
  {
    return STATUS_HOOG;
  }

  return STATUS_EXTREEM;

} //   classifyPm25()

static const char* statusText(AirStatus s)
{
  switch (s)
  {
  case STATUS_GEMIDDELD:
    return "GEMIDDELD";
  case STATUS_HOOG:
    return "HOOG";
  default:
    return "EXTREEM";
  }

} //   statusText()

// ===================== ESP32 radio shutoff =====================

static void disableRadiosAsap()
{
  // — Ensure Arduino WiFi is off
  WiFi.mode(WIFI_OFF);
  WiFi.disconnect(true);

  // — Stop WiFi driver (ignore errors if not started yet)
  (void)esp_wifi_stop();
  (void)esp_wifi_deinit();

  // — Stop Bluetooth controller if present
  btStop();
  (void)esp_bt_controller_disable();
  (void)esp_bt_controller_deinit();

} //   disableRadiosAsap()

// ===================== I2C helpers =====================

static void i2cInit()
{
  // — Initialize I2C once, early (shared by BMP and SPS)
  Wire.begin(pinSpsSda, pinSpsScl);
  delay(10);
  Wire.setClock(100000);

  // — Prevent rare deadlocks on ESP32 if a device holds the bus
  Wire.setTimeOut(50);

  // — Bind Sensirion SPS30 driver to Wire
  sensirion_i2c_init(Wire);

  Serial.printf("I2C init: SDA=%u SCL=%u\n",
                (unsigned)pinSpsSda,
                (unsigned)pinSpsScl);

} //   i2cInit()

static bool i2cScanHasAddress(uint8_t targetAddr)
{
  Serial.printf("I2C scan start\n");

  uint8_t found = 0;
  bool targetFound = false;

  for (uint8_t addr = 1; addr < 127; addr++)
  {
    Wire.beginTransmission(addr);
    uint8_t err = (uint8_t)Wire.endTransmission(true);

    if (err == 0)
    {
      Serial.printf("I2C device found at 0x%02X\n", (unsigned)addr);
      found++;

      if (addr == targetAddr)
      {
        targetFound = true;
      }
    }

    delay(2);
    yield();
  }

  Serial.printf("I2C scan done (%u devices)\n", (unsigned)found);

  return targetFound;

} //   i2cScanHasAddress()

// ===================== UART passthrough =====================

static void spsUartPassthroughInit()
{
  // — PMS UART: 115200 8N1
  spsUart.begin(115200, SERIAL_8N1, pinPms5003UartRx, pinPms5003UartTx);

  Serial.printf("PMS UART passthrough on UART2: RX=%d TX=%d\n",
                (int)pinPms5003UartRx, (int)pinPms5003UartTx);

} //   spsUartPassthroughInit()

static void spsUartPassthroughLoop()
{
  while (spsUart.available() > 0)
  {
    int c = spsUart.read();
    Serial.write((uint8_t)c);
  }

} //   spsUartPassthroughLoop()

// ===================== Battery reading =====================

#ifndef BAT_CAL_GAIN
//--Battery calibration gain (default: no correction)
#define BAT_CAL_GAIN 1.0f
#endif

#ifndef BAT_CAL_OFFSET
//--Battery calibration offset in volts (default: no correction)
#define BAT_CAL_OFFSET 0.0f
#endif

static float readBatteryVoltage()
{
  //--Read calibrated ADC voltage in millivolts (ESP32 eFuse based)
  uint32_t mv = (uint32_t)analogReadMilliVolts(pinBatAdc);
  float vAdc = (float)mv / 1000.0f;

  //--Default assumes a 2:1 divider (ADC sees Vbat/2)
  float vBatRaw = vAdc * 2.0f;

  //--Apply calibration (derived from measured points)
  float vBatCal = (vBatRaw * (float)BAT_CAL_GAIN) + (float)BAT_CAL_OFFSET;

  return vBatCal;

} //   readBatteryVoltage()

static uint8_t batteryPercentFromVoltage(float vbat)
{
  //--Typical 1S Li-ion (18650) voltage-to-SOC curve (approx.)
  //--Note: Under load the voltage sag can make SOC appear lower.
  struct Vp
  {
    float v;
    uint8_t p;
  };

  static const Vp curve[] =
      {
          {4.20f, 100},
          {4.15f, 95},
          {4.11f, 90},
          {4.08f, 85},
          {4.02f, 80},
          {3.98f, 75},
          {3.95f, 70},
          {3.91f, 65},
          {3.87f, 60},
          {3.85f, 55},
          {3.82f, 50},
          {3.79f, 45},
          {3.77f, 40},
          {3.74f, 35},
          {3.72f, 30},
          {3.70f, 25},
          {3.68f, 20},
          {3.65f, 15},
          {3.62f, 10},
          {3.58f, 5},
          {3.50f, 0}};

  //--Clamp above max
  if (vbat >= curve[0].v)
  {
    return 100;
  }

  //--Clamp below min
  const uint8_t last = (uint8_t)(sizeof(curve) / sizeof(curve[0]) - 1);
  if (vbat <= curve[last].v)
  {
    return 0;
  }

  //--Find segment and interpolate
  for (uint8_t i = 0; i < last; i++)
  {
    float vHigh = curve[i].v;
    float vLow = curve[i + 1].v;

    if (vbat <= vHigh && vbat >= vLow)
    {
      uint8_t pHigh = curve[i].p;
      uint8_t pLow = curve[i + 1].p;

      float t = (vbat - vLow) / (vHigh - vLow);
      float p = (float)pLow + t * ((float)pHigh - (float)pLow);

      if (p < 0.0f)
      {
        p = 0.0f;
      }

      if (p > 100.0f)
      {
        p = 100.0f;
      }

      return (uint8_t)(p + 0.5f);
    }
  }

  //--Should never happen
  return 0;

} //   batteryPercentFromVoltage()

static String formatBatteryLine(float vbat, uint8_t pct)
{
  // — Example: "4.1V (78%)"
  char buf[48];
  snprintf(buf, sizeof(buf), "%.1fV (%u%%)", vbat, pct);
  return String(buf);

} //   formatBatteryLine()

static void updateBatteryNow(const char* reason)
{
  // — Read and render battery line immediately
  float vbat = readBatteryVoltage();
  uint8_t pct = batteryPercentFromVoltage(vbat);

  batteryVoltageLast = vbat;
  batteryPercentLast = pct;

  batteryText = formatBatteryLine(vbat, pct);
  batteryText = truncateToChars(batteryText, 12);

  Serial.printf("Battery (%s): %.2f V (%u%%)\n", reason, vbat, pct);

} //   updateBatteryNow()

// ===================== BMP280 helpers =====================

static bool bmpInit()
{
  // — BMP280 can be at 0x76 or 0x77; your chip responds at 0x76
  if (!bmp.begin(0x76))
  {
    if (!bmp.begin(0x77))
    {
      return false;
    }
  }

  // — Reasonable default config (fast enough, stable)
  bmp.setSampling(Adafruit_BMP280::MODE_NORMAL,
                  Adafruit_BMP280::SAMPLING_X2,  // temp
                  Adafruit_BMP280::SAMPLING_X16, // pressure
                  Adafruit_BMP280::FILTER_X16,
                  Adafruit_BMP280::STANDBY_MS_125);

  return true;

} //   bmpInit()

static void updateEnvNow(const char* reason)
{
  // — Format: "21.3C 1013h" (no RH on BMP280)
  if (!bmpOk)
  {
    envText = "-";
    return;
  }

  float tC = bmp.readTemperature();
  float pHpa = bmp.readPressure() / 100.0f;

  if (!isfinite(tC) || !isfinite(pHpa))
  {
    envText = "-";
    return;
  }

  char buf[24];
  snprintf(buf, sizeof(buf), "%.1fC %.0fhPa", tC, pHpa);

  envText = truncateToChars(String(buf), 18);

  Serial.printf("BMP (%s): T=%.1f*C P=%.0fhPa\n", reason, tC, pHpa);

} //   updateEnvNow()

// ===================== E-paper helpers =====================

static void epdInit()
{
  // — Configure control pins
  pinMode(pinEpdCs, OUTPUT);
  digitalWrite(pinEpdCs, HIGH);

  pinMode(pinEpdDc, OUTPUT);
  digitalWrite(pinEpdDc, LOW);

  pinMode(pinEpdRst, OUTPUT);
  digitalWrite(pinEpdRst, HIGH);

  // — BUSY input with pull-up (board is open drain)
  pinMode(pinEpdBusy, INPUT_PULLUP);

  // — Map SPI pins explicitly (MISO may be -1)
  SPI.begin(pinEpdSck, pinEpdMiso, pinEpdMosi, pinEpdCs);

  // — Manual reset pulse (some boards need this)
  digitalWrite(pinEpdRst, LOW);
  delay(20);
  digitalWrite(pinEpdRst, HIGH);
  delay(50);

  Serial.printf("EPD BUSY before init: %d\n", digitalRead(pinEpdBusy));

  // — Init display (GxEPD2 controls SPI transactions internally)
  display.init(115200, true, 2, false);

  if (epdRotation <= 3)
  {
    display.setRotation(epdRotation);
  }
  else
  {
    Serial.printf("Warning: invalid E_PAPER_ROTATION=%u, fallback to 1\n", (unsigned)epdRotation);
    display.setRotation(1);
  }

  display.setTextColor(GxEPD_BLACK);
  display.setFullWindow();

} //   epdInit()

static void uiUpdateLinePartial9pt(int16_t yBaseline, const String& text)
{
  // — Clear a full-width band and print one line in 9pt
  const int16_t bandHeight = 22;

  int16_t x = 0;
  int16_t y = yBaseline - bandHeight + 2;
  int16_t w = display.width();
  int16_t h = bandHeight;

  if (y < 0)
  {
    y = 0;
  }

  if ((y + h) > display.height())
  {
    h = display.height() - y;
  }

  display.setPartialWindow(x, y, w, h);

  displayRefreshInProgress = true;
  display.firstPage();
  do
  {
    display.fillRect(x, y, w, h, GxEPD_WHITE);

    display.setTextColor(GxEPD_BLACK);
    display.setFont(&FreeMonoBold9pt7b);
    display.setCursor(ui.xText, yBaseline);
    display.print(text);

  } while (display.nextPage());
  displayRefreshInProgress = false;

} //   uiUpdateLinePartial9pt()

static void uiUpdatePmValuesPartial12pt()
{
  // — Clear band for PM values (12pt)
  const int16_t bandHeight = 36;

  int16_t x = 0;
  int16_t y = ui.yPmValues - bandHeight + 4;
  int16_t w = display.width();
  int16_t h = bandHeight;

  if (y < 0)
  {
    y = 0;
  }

  if ((y + h) > display.height())
  {
    h = display.height() - y;
  }

  display.setPartialWindow(x, y, w, h);

  displayRefreshInProgress = true;
  display.firstPage();
  do
  {
    display.fillRect(x, y, w, h, GxEPD_WHITE);

    display.setTextColor(GxEPD_BLACK);
    display.setFont(&FreeMonoBold12pt7b);

    display.setCursor(ui.xPmCol1, ui.yPmValues);
    display.print(pm1Text);

    display.setCursor(ui.xPmCol2, ui.yPmValues);
    display.print(pm25Text);

    display.setCursor(ui.xPmCol3, ui.yPmValues);
    display.print(pm10Text);

  } while (display.nextPage());
  displayRefreshInProgress = false;

} //   uiUpdatePmValuesPartial12pt()

static void uiUpdatePmTextCenteredPartial12pt(const String& text)
{
  // — Clear PM values band and draw one centered text line in 12pt
  const int16_t bandHeight = 36;

  int16_t x = 0;
  int16_t y = ui.yPmValues - bandHeight + 4;
  int16_t w = display.width();
  int16_t h = bandHeight;

  if (y < 0)
  {
    y = 0;
  }

  if ((y + h) > display.height())
  {
    h = display.height() - y;
  }

  int16_t textX = ui.xPmCol1;
  int16_t textBoundsX = 0;
  int16_t textBoundsY = 0;
  uint16_t textBoundsW = 0;
  uint16_t textBoundsH = 0;

  display.setFont(&FreeMonoBold12pt7b);
  display.getTextBounds(text.c_str(), 0, ui.yPmValues, &textBoundsX, &textBoundsY, &textBoundsW, &textBoundsH);

  if (textBoundsW < (uint16_t)display.width())
  {
    textX = (((int16_t)display.width() - (int16_t)textBoundsW) / 2) - textBoundsX;
  }

  display.setPartialWindow(x, y, w, h);

  displayRefreshInProgress = true;
  display.firstPage();
  do
  {
    display.fillRect(x, y, w, h, GxEPD_WHITE);

    display.setTextColor(GxEPD_BLACK);
    display.setFont(&FreeMonoBold12pt7b);
    display.setCursor(textX, ui.yPmValues);
    display.print(text);

  } while (display.nextPage());
  displayRefreshInProgress = false;

} //   uiUpdatePmTextCenteredPartial12pt()

static void uiDrawAllFull()
{
  display.setFullWindow();

  displayRefreshInProgress = true;
  display.firstPage();
  do
  {
    display.fillScreen(GxEPD_WHITE);
    display.setTextColor(GxEPD_BLACK);

    // — Battery line (9pt)
    display.setFont(&FreeMonoBold9pt7b);
    display.setCursor(ui.xText, ui.yBattery);
    display.print(String("Bat: ") + batteryText);

    // — BME line (9pt)
    display.setCursor(ui.xText, ui.yEnv);
    display.print(String("T: ") + envText);

    // — PM header (9pt)
    display.setFont(&FreeMonoBold9pt7b);

    display.setCursor(ui.xPmCol1, ui.yPmHeader);
    display.print("PM1");

    display.setCursor(ui.xPmCol2, ui.yPmHeader);
    display.print("PM2.5");

    display.setCursor(ui.xPmCol3, ui.yPmHeader);
    display.print("PM10");

    // — PM values (12pt)
    display.setFont(&FreeMonoBold12pt7b);

    display.setCursor(ui.xPmCol1, ui.yPmValues);
    display.print(pm1Text);

    display.setCursor(ui.xPmCol2, ui.yPmValues);
    display.print(pm25Text);

    display.setCursor(ui.xPmCol3, ui.yPmValues);
    display.print(pm10Text);

    // — Status/message (9pt)
    display.setFont(&FreeMonoBold9pt7b);
    display.setCursor(ui.xText, ui.yMessage);
    display.print(messageText);

  } while (display.nextPage());
  displayRefreshInProgress = false;

} //   uiDrawAllFull()

static void uiDrawWaitingForUpdateFull(const String& hostName, const String& ipAddress)
{
  display.setFullWindow();

  displayRefreshInProgress = true;
  display.firstPage();
  do
  {
    display.fillScreen(GxEPD_WHITE);
    display.setTextColor(GxEPD_BLACK);

    display.setFont(&FreeMonoBold9pt7b);
    display.setCursor(ui.xText, 70);
    display.print("WAITING FOR");

    display.setCursor(ui.xText, 96);
    display.print("UPDATE");

    display.setCursor(ui.xText, 136);
    display.print(hostName);

    display.setCursor(ui.xText, 164);
    display.print(ipAddress);

  } while (display.nextPage());
  displayRefreshInProgress = false;

} //   uiDrawWaitingForUpdateFull()

static void uiDrawCenteredLine9pt(int16_t yBaseline, const String& text)
{
  int16_t textBoundsX = 0;
  int16_t textBoundsY = 0;
  uint16_t textBoundsW = 0;
  uint16_t textBoundsH = 0;

  display.setFont(&FreeMonoBold9pt7b);
  display.getTextBounds(text.c_str(), 0, yBaseline, &textBoundsX, &textBoundsY, &textBoundsW, &textBoundsH);

  int16_t textX = ui.xText;
  if (textBoundsW < (uint16_t)display.width())
  {
    textX = (((int16_t)display.width() - (int16_t)textBoundsW) / 2) - textBoundsX;
  }

  display.setCursor(textX, yBaseline);
  display.print(text);

} //   uiDrawCenteredLine9pt()

static void uiDrawWifiPortalStartedFull(const String& apName)
{
  display.setFullWindow();

  displayRefreshInProgress = true;
  display.firstPage();
  do
  {
    display.fillScreen(GxEPD_WHITE);
    display.setTextColor(GxEPD_BLACK);

    uiDrawCenteredLine9pt(52, String("WiFi Portal"));
    uiDrawCenteredLine9pt(78, String("Started"));
    uiDrawCenteredLine9pt(104, String("Waiting for user"));
    uiDrawCenteredLine9pt(130, String("input"));
    uiDrawCenteredLine9pt(156, apName);

  } while (display.nextPage());
  displayRefreshInProgress = false;

} //   uiDrawWifiPortalStartedFull()

static void uiUpdateBatteryPartial()
{
  uiUpdateLinePartial9pt(ui.yBattery, String("Bat: ") + batteryText);

} //   uiUpdateBatteryPartial()

static void uiUpdateEnvPartial()
{
  uiUpdateLinePartial9pt(ui.yEnv, String("T: ") + envText);

} //   uiUpdateEnvPartial()

static void uiUpdatePmPartial()
{
  uiUpdatePmValuesPartial12pt();

} //   uiUpdatePmPartial()

static void uiUpdateMessagePartial()
{
  // — Clear from status band down to panel bottom to remove descender artifacts
  int16_t x = 0;
  int16_t y = ui.yMessage - 24;
  int16_t w = display.width();
  int16_t h = display.height() - y;

  if (y < 0)
  {
    y = 0;
    h = display.height();
  }

  if (h < 1)
  {
    h = 1;
  }

  display.setPartialWindow(x, y, w, h);

  displayRefreshInProgress = true;
  display.firstPage();
  do
  {
    display.fillRect(x, y, w, h, GxEPD_WHITE);

    display.setTextColor(GxEPD_BLACK);
    display.setFont(&FreeMonoBold9pt7b);
    display.setCursor(ui.xText, ui.yMessage);
    display.print(messageText);

  } while (display.nextPage());
  displayRefreshInProgress = false;

} //   uiUpdateMessagePartial()

static void uiUpdateDynamicAll()
{
  uiUpdateBatteryPartial();
  uiUpdateEnvPartial();
  uiUpdatePmPartial();
  uiUpdateMessagePartial();

} //   uiUpdateDynamicAll()

static void epdEnterLowPowerMode()
{
  // — Ensure panel high-voltage stage is turned off before hard power cut
  display.powerOff();

  // — Put controller in deep sleep to preserve image contrast until VCC drops
  display.hibernate();

} //   epdEnterLowPowerMode()

// ===================== SPS helpers =====================

static bool spsInitAndStart()
{
  // — Probe sensor (Sensirion driver bound in i2cInit())
  if (sps30_probe() != 0)
  {
    return false;
  }

  // — Start measurement mode
  if (sps30_start_measurement() != 0)
  {
    return false;
  }

  return true;

} //   spsInitAndStart()
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
void loop()
{
  serviceBackgroundTasks();
  processWifiStartRequest();
  wifiManagerExt.handle();
  processSwitchOffRequest();

  if (wifiManagerExt.isServiceModeActive())
  {
    delay(2);
    return;
  }

  runMainStateMachine();
  processSwitchOffRequest();

} //   loop()

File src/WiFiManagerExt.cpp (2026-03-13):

/*** Last Changed: 2026-03-13 - 12:21 ***/
#include "WiFiManagerExt.h"

#include <WiFi.h>
#include <ArduinoOTA.h>
#include <WiFiManager.h>

WiFiManagerExt* WiFiManagerExt::instance = nullptr;

WiFiManagerExt::WiFiManagerExt()
{
  instance = this;
  portalStartCallback = nullptr;
  connectedCallback = nullptr;
  otaStartCallback = nullptr;
  otaEndCallback = nullptr;
  startRequested = false;
  serviceModeActive = false;
  otaInProgress = false;
  otaReady = false;
  wifiSettingsErased = false;
}

void WiFiManagerExt::setPortalStartCallback(PortalStartCallback callback)
{
  portalStartCallback = callback;
}

void WiFiManagerExt::setOtaStartCallback(SimpleCallback callback)
{
  otaStartCallback = callback;
}

void WiFiManagerExt::setConnectedCallback(ConnectedCallback callback)
{
  connectedCallback = callback;
}

void WiFiManagerExt::setOtaEndCallback(SimpleCallback callback)
{
  otaEndCallback = callback;
}

void WiFiManagerExt::requestStart()
{
  startRequested = true;
}

void WiFiManagerExt::handle()
{
  if (startRequested)
  {
    startRequested = false;
    startServiceMode();
  }

  if (otaReady)
  {
    ArduinoOTA.handle();
  }
}

bool WiFiManagerExt::isServiceModeActive() const
{
  return serviceModeActive;
}

bool WiFiManagerExt::isOtaInProgress() const
{
  return otaInProgress;
}

String WiFiManagerExt::getApNamePreview() const
{
  return makeApName();
}

String WiFiManagerExt::makeApName() const
{
  uint8_t mac[6] = {0};
  WiFi.macAddress(mac);

  char buf[24];
  snprintf(buf, sizeof(buf), "HHPMS-%02X%02X%02X", (unsigned)mac[3], (unsigned)mac[4], (unsigned)mac[5]);
  return String(buf);
}

void WiFiManagerExt::startServiceMode()
{
  if (serviceModeActive)
  {
    return;
  }

  WiFi.mode(WIFI_STA);

  WiFiManager wifiManager;
  apName = makeApName();

#ifdef WIFI_ERASE
  if (!wifiSettingsErased)
  {
    Serial.printf("WiFiManager: erasing saved WiFi settings (WIFI_ERASE)\n");
    wifiManager.resetSettings();
    WiFi.disconnect(true, true);
    wifiSettingsErased = true;
  }
#endif

  wifiManager.setAPCallback(onPortalStartThunk);
  wifiManager.setConfigPortalBlocking(true);

  bool connected = wifiManager.autoConnect(apName.c_str());
  if (!connected)
  {
    Serial.printf("WiFiManager: connect/portal ended without WiFi connection\n");
    return;
  }

  setupOta();
  serviceModeActive = true;

  if (connectedCallback != nullptr)
  {
    connectedCallback(apName, WiFi.localIP().toString());
  }

  Serial.printf("WiFi connected: %s\n", WiFi.localIP().toString().c_str());
}

void WiFiManagerExt::setupOta()
{
  ArduinoOTA.setHostname(apName.c_str());
  ArduinoOTA.onStart(onOtaStartThunk);
  ArduinoOTA.onEnd(onOtaEndThunk);
  ArduinoOTA.onError(onOtaErrorThunk);
  ArduinoOTA.begin();

  otaReady = true;

  Serial.printf("OTA ready (hostname: %s)\n", apName.c_str());
}

void WiFiManagerExt::onPortalStartThunk(WiFiManager* wifiManager)
{
  if (instance == nullptr)
  {
    return;
  }

  String ssid = instance->apName;
  if ((wifiManager != nullptr) && (wifiManager->getConfigPortalSSID() != nullptr))
  {
    ssid = String(wifiManager->getConfigPortalSSID());
  }

  if (instance->portalStartCallback != nullptr)
  {
    instance->portalStartCallback(ssid);
  }
}

void WiFiManagerExt::onOtaStartThunk()
{
  if (instance == nullptr)
  {
    return;
  }

  instance->otaInProgress = true;

  if (instance->otaStartCallback != nullptr)
  {
    instance->otaStartCallback();
  }
}

void WiFiManagerExt::onOtaEndThunk()
{
  if (instance == nullptr)
  {
    return;
  }

  instance->otaInProgress = false;

  if (instance->otaEndCallback != nullptr)
  {
    instance->otaEndCallback();
  }
}

void WiFiManagerExt::onOtaErrorThunk(ota_error_t error)
{
  (void)error;

  if (instance == nullptr)
  {
    return;
  }

  instance->otaInProgress = false;

  if (instance->otaEndCallback != nullptr)
  {
    instance->otaEndCallback();
  }
}

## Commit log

2026-02-11 Many inprovements
    [handheldAerosolSensor.kicad_pcb, handheldAerosolSensor.kicad_sch]
2026-02-11 refactor(ui): redesign PM display to column-based layout
    Major UI redesign and configuration adjustments:
    **Display Layout:**
    - Restructure PM values display from row-based to column-based format
    - Replace separate yPm1/yPm25/yPm10 positions with unified yPmHeader/yPmValues
    - Change PM layout from xPmLabel/xPmValue to xPmCol1/xPmCol2/xPmCol3
    - Add FreeMonoBold18pt7b font for larger value display
    - Refactor uiUpdatePmLinePartial12pt() to uiUpdatePmValuesPartial12pt()
    - Remove uiDrawAllFull() function (no longer needed)
    - Update all UI coordinate positions for new layout
    **Configuration Changes:**
    - Increase sampleIntervalMs from 1000 to 2500ms for better sampling cadence
    [main.cpp]
2026-02-15 KiCad aanpassingen
    [handheldAerosolSensor.kicad_pcb, handheldAerosolSensor.kicad_sch, untitled.kicad_sch]
2026-02-15 Add power indicator LED (D201) with supporting components to the PCB design: - Add 1206 SMD power LED with current limiting resistor - Add new nets for LED connections (Net-(C201-Pad1), Net-(D201-A))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
    [freerouting.dsn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]
2026-02-15 Repositioned all mounting holes (H1-H5, H201-H204) to align with updated mechanical constraints. Updated board edge graphics and coordinates to match the new hole positions. Changes improve PCB fitme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
    [handheldAerosolSensor.kicad_pcb]
2026-03-08 - Refactor sensor code from SPS UART to PMS5003 UART throughout main.cpp - Add displayRefreshInProgress flag for better UI state tracking - Update pin naming conventions to reflect PMS5003 hardware
2026-03-08 feat: improve PM value display formatting with tiered precision
    Updated formatPmLine() to display particulate matter values with
    context-appropriate precision:
    - Values <100: shown with one decimal place (e.g., "45.3")
    - Values 100-999: shown as integers (e.g., "342")
    - Values >999: capped at "999" to prevent display overflow
    This improves readability and makes better use of limited display
    space while maintaining appropriate precision for each value range.
    Version bumped to v0.9.2.
    [main.cpp]
2026-03-08 feat: add configurable e-paper display rotation
    Add E_PAPER_ROTATION build flag to allow configuring display orientation
    (0-3) with validation and fallback to default rotation. Also adjust PM
    sensor validation limits from 2000 to 1000 µg/m³ for more realistic
    range checking.
    - Add E_PAPER_ROTATION build flag in platformio.ini (default: 0)
    - Implement rotation validation in epdInit() with fallback to rotation 1
    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
2026-03-12 KiCAD design openScad design
    [YAPPgenerator_v3.0.2.scad, YAPPgenerator_v3.3.8.scad, freerouting.dsn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]
2026-03-12 KiCAD changed
2026-03-13 Major version release with the following changes: - Add ePaper display PCB configuration and mounting cutouts - Update PCB reference file name to handheldAerosolSensorPCB.stl - Refine cutout dimensio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
    [handheldAerosolSensor.scad]
2026-03-13 Add support for PMS5003 sensor as an alternative to SPS30: - Introduce ParticleSensorType enum to distinguish between sensor types - Add PMS5003 pin definitions (SET, RESET) and control functions - I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
    [main.cpp]
2026-03-13 - Add battery protection at startup (shutdown if < 3.4V) - Display "BATTERY LOW" warning before shutdown when < 3.6V - Store last battery voltage/percentage for later checks - Fix message area partia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
    [main.cpp]
2026-03-13 Add WiFi configuration and Over-The-Air (OTA) update capabilities to the handheld aerosol sensor:
    - Add WiFiManager library dependency for WiFi credential management
    - Create new PlatformIO environment (esp32dev_ota) for OTA uploads
    - Implement WiFi portal UI screen to guide users during configuration
    - Add OTA update waiting screen with hostname and IP display
    - Consolidate PlatformIO environments by removing separate test configurations
    - Add WiFi erase build flag option for resetting credentials
    - Implement callback handlers for WiFi portal and OTA events
    [WiFiManagerExt.cpp, main.cpp]
2026-03-13 - Bump version from v0.10.3 to v1.0.0 in firmware - Reorganize 3D model file paths to documents directory - Add ePaper display model reference for visualization - Adjust ePaper display cutout positio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
    [SPS30Holder.stl, ePaper.stl, handheldAerosolSensor.scad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]
